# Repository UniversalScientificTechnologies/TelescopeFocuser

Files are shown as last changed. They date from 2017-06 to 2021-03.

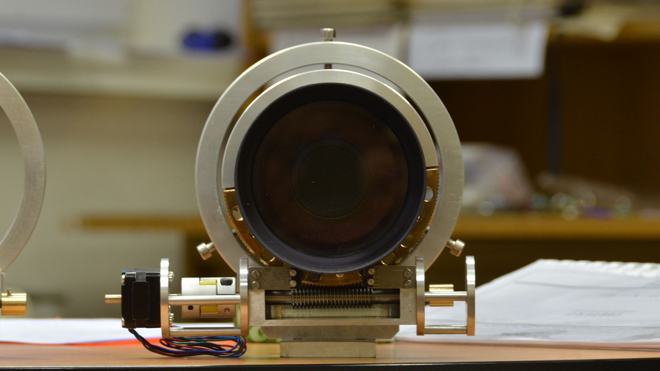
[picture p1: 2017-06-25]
DOC/SRC/img/DSC_8368x.JPG

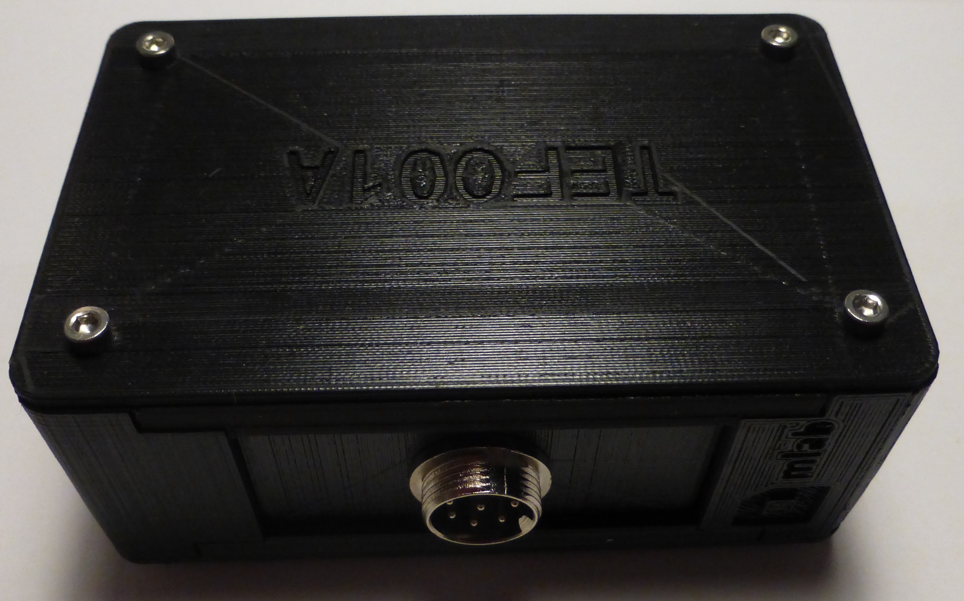
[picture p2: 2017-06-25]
DOC/SRC/img/P1020736.JPG

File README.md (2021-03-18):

# TelescopeFocuser
Telescope focuser with position feedback - TEFO01B

TEFO01B D50 telescope

# Mlab modules
 * HBSTEP01B
 * I2CSPI01A
 * RPS01A
 * USBI2C (optional)
 * POWERSOURCE

# Dependencies
 * [PyMLAB](https://github.com/MLAB-project/pymlab) with [HIDAPI](https://github.com/trezor/cython-hidapi)
 * [Axis class](https://github.com/MLAB-project/axis)

# Versions
There are two versions of code - the "simple one" (`TEFO_abspos.py`) and the "responsive one" (`TEFO_abspos_responsive.py`).
They only differ in the communication protocol and general behaviour, the other aspects are the same.

## The "simple" version (```TEFO_abspos.py```)
### Behaviour
Every successully recieved message is immediately confirmed with a simple response (see below).
The reply of the commands is sent after the completion (e.g., after the movement was accomplished). The deamon is not accepting commands until the previous operation is finished.

### Communication (UDP messages)
 * ```H``` Go to home position (defined in config json), reply: ```Home;<miss_calib>;```
 * ```CMxxxx``` parameter - calibrate and move to position in promile (0-1000), reply: ```CalibMove;<miss_calib>;```
 * ```Mxxxx``` move to position (without calibration), reply: ```Move;<miss_calib>;```
 * ```C``` run calibration, None reply
 * ```S``` Status, answer is in format ```<miss_calib>;<target>```

After every succesful recieve of message, inmediately command is confirmed with ```ACK;<command>;<senders_ip>;```

## The "responsive" version (```TEFO_abspos_responsive.py```)
### Behaviour and communication (UDP messages)
 * The daemon is responsive, i.e. every command is executed "in background", the execution does not wait for the completion.
 * The daemon never initiates any message, the communication is based on strict question/answer scheme.
 * Answer to any command consists of:
   * The command which initiated the answer (including the numerical ID)
   * Status of the request (accepted/duplicity/wrong)
   * Actual state of a motor (idle/moving/calibrating)
   * Result of the last movement (0=ok/1=fail)
   * Actual position (works even within the movement)
   * Actually set target position (if it does not equal actual position, the state of a motor is idle and the last movement's result is ok, it's obvious that the unit had been restarted; it's up to a client to send a recalibration command)
   * Expected time [s] till the end of ongoing move operation, only useful when state of a motor is "moving" (the lower estimate, typically takes ~0.1-0.2s more time to finish).
 * To take care of lossy UDP protocol, we use a simple logic: the daemon remembers the last command's ID. When the new command has the same ID, we expect that the client didn't receive the response, so we don't perform any operation, just respond the "duplicity" status and report the actual state. The ID is generated by a client, the daemon remembers only the ID of last command and doesn't take care of IP address. Which is OK for sparse communication with typically one client.
 * We use these commands:
   | Command | Description |
   | --- | --- |
   | `M<number_int>` | move to position |
   | `CM<number_int>` | calibrate and move to position |
   | `C` | calibrate and move to last or "home" position |
   | `S` | send status report |
   | `STOP` | stop all movements (emergency command for testing purposes) |
 * Structure of client's commands:
   `<ID_int16> <command>`
 * Structure of the response:
   `<ID_int16> <command> <request-status_string> <motor-status_string> <last-movement-result_int> <actual-ABS-position_int> <set-ABS-position_int> <time-to-moveend_float>`
 * The interruptibility:
   * `STOP` quits any movement
   * the calibration may be interrupted by nothing but stop
   * move comands may be interrupted by any command
   * non-accepted commands (which violated the interruptibility rules) cause response status "wrong"

## Connection
```nc -u localhost <port>```

# Configuration
Configuration is done by config [.json]() file.

```json

{
    "pymlab":{
        "i2c":{
            "device": "hid",
            "serial": "003347BC"
        },
        "bus": [
            { 
                "name":"spi", 
                "type":"i2cspi"
            },
            {
                "name": "encoder",
                "type": "rps01"
            }
        ]
    },
    "tefo":{
        "dir": 0,
        "lenght": 3300,
        "home": 1650,
        "speed": 100,
        "_lenght": 26500,
        "_home": 13250,
        "home_speed": 20 
    },
    "connection":{
        "ip": "127.0.0.1",
        "port": 5000
    }
}

```

# Installation of the systemd service
The example systemd service files are placed in SW/systemd.
The installation is simple, just copy the files to /etc/systemd/system 
and edit them to meet your needs (path, configurations of instances desired 
to run etc).

To apply changes made in the definition of systemd files:\
```systemctl daemon-reload```

To autostart the daemons after the boot:\
```systemctl enable mlab-tefo.target```

To manage an individual instance of service or the whole bunch use standard
systemctl interface, e.g.:\
```systemctl start mlab-tefo.target```\
```systemctl status mlab-tefo@focuser_D50_WF.service```\
```systemctl stop mlab-tefo@focuser_D50_main.service```

The output is redirected to the journal service, you can read it using the ```journalctl``` command.

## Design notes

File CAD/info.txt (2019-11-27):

Boxy pro TEFO01A

TEFO01A_BOX01A
-box vycházející z BASEBOX01A
-určen pro první část TEFO01A - HBSTEP01B, I2CSPI01A

TEFO01A_BOX02A_I2C
-box vycházející z BASEBOX01A
-určen pro druhou část ve variantě s I2C. Obsahuje moduly USBI2C01A,UNIPOWER02A, MIC338 (konektor)

TEFO01A_BOX02A_RS232
-box vycházející z BASEBOX01A
-určen pro druhou část ve variantě s RS232. Obsahuje moduly R232SINGLE01A, I2C232V01A, UNIPOWER02A, MIC338 (konektor)

Boxy pro TEFO01C

TEFO01C_BOX01A
-box vycházející z BASEBOX02A
-určen pro TEFO01C - HBSTEP01B, I2CSPI01A, UNIPOWER02A, USBI2C01A a konektor MIC338 pro připojení motoru.

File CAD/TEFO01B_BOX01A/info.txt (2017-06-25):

Box derived from BASEBOX01A
Intended for motor part of TEFO01B  with HBSTEP01B, I2CSPI01A,I2CDIFF01A modules

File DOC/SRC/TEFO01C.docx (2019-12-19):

Fokuser pro dalekohledy řízený přes USB

Jan Chroust, Roman Dvořák

## Konstrukce je určena pro automatické ostření dalekohledů. Elektronické řízení krokového motoru využívá mikrokrokování, které eliminuje vibrace generované motorem. Konstrukce počítá s koncovými spínači.

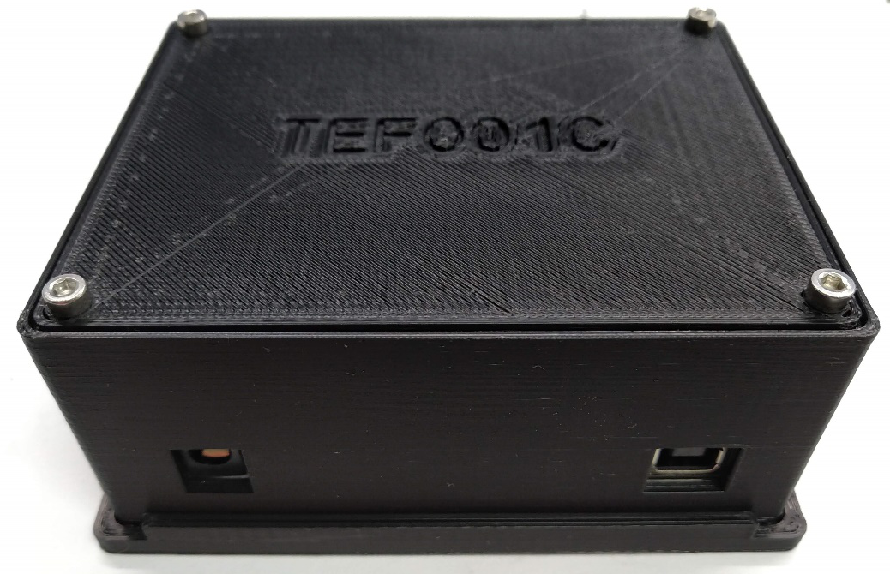
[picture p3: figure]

# 1. Technické parametry

Parametr | Hodnota | Poznámka
Napájení | 8 V – 45 V
Rozhraní | USB | Po dohodě
Rozměry | Dle zvolené koncepce

# 2. ¨ Popis konstrukce

### 2.1.1. Úvod

Zařízení TEFO01C řeší pouze elektronickou část fokuseru. Veškerou mechaniku je potřeba si vytvořit. K elektronice je možné připojit krokový motor v rozsahu napájecího napětí 8 V – 45 V. Mechanická konstrukce musí obsahovat dva koncové spínače, které budou mít jednu stranu kontaktů propojenou (po stisku koncového spínače musí být kontakt ve stavu sepnutém).

V případě zájmu o dodání TEFO01C nás prosím kontaktujte, protože konstrukce může být přizpůsobena požadavků. Je možné dodání více senzorů, ovládačů korkových motorů, nebo změnit komunikační rozhraní.

### 2.1.2. Potřebné moduly

Pro variantu řízenou USB: HBSTEP01B (s C pro 50V, jumper na ADCIN a VREG-VDD), I2CSPI01A, USBI2C01A (jumper na volbu 3V3 pro napájení I2C hřebínku a mezi VIO-3,3V), UNIPOWER02A(12V verze), TEFO01C_BOX01A

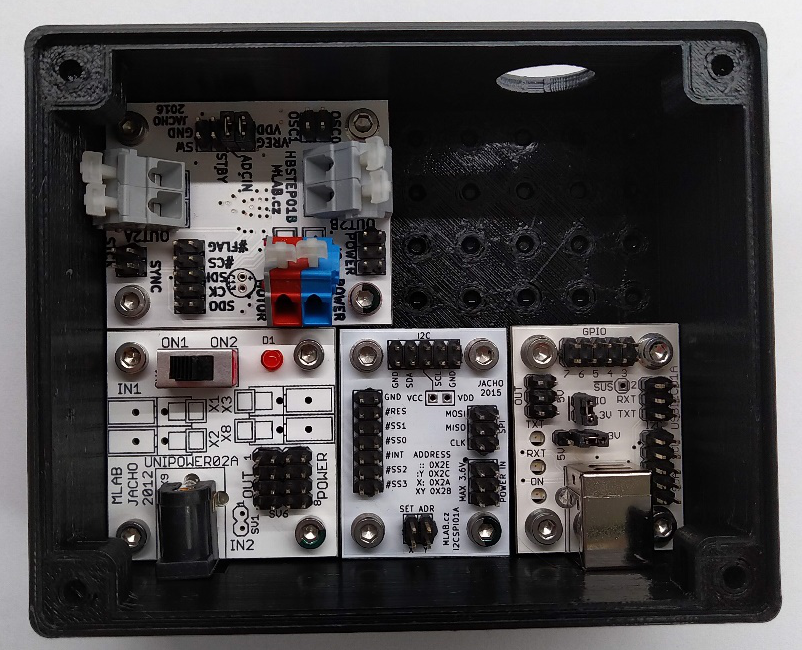
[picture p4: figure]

### 2.1.3. Propojení modulů

#### Zapojení konektoru MIC338

PIN – barva délka – význam vodiče – zapojení na modul

PIN 1 – oranžová 10 cm OUT1A - HBSTEP01B

PIN 2 – černá 10 cm – OUT2A - HBSTEP01B

PIN 3 – bílá 10 cm - OUT1B - HBSTEP01B

PIN 4 – modrá 10 cm - OUT2B - HBSTEP01B

PIN 5 – fialová 10 cm – první spínač GPIO0 (TXT) – USBI2C01A

PIN 6 – šedá 10cm – druhý spínač GPIO1 (RXT) – USBI2C01A

PIN 7 – zelná 10cm – střed mezi vypínači SW– HBSTEP01B

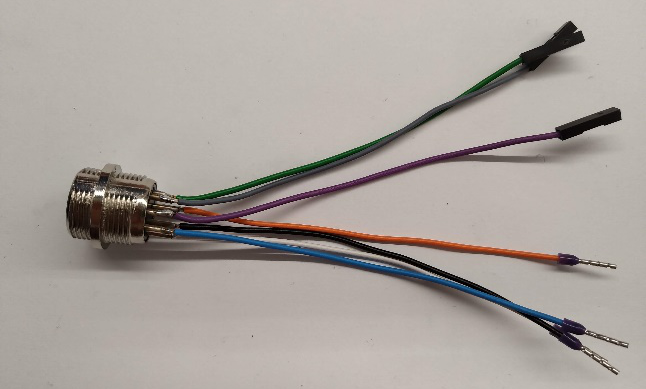
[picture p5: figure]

#### Propojení mezi moduly HBSTEP01B a I2CSPI01A

I2CSPI01A – HBSTEP01B

#SS0 - #CS – zelená 10cm

CLK – CK - bílá 10cm

MISO – SDO – šedá 10cm

MOSI – SDI – hnědá 10cm

Na I2CSPI01A vyvést vodičem napájení POWER IN na I2C hřebínek. Kvůli pull-up a napájení. 10Cm oranžová

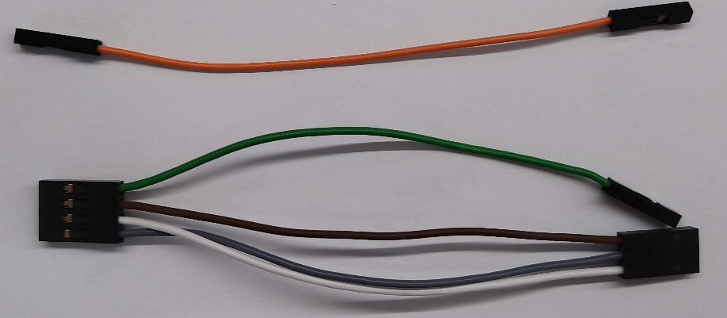
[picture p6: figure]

#### Propojení mezi USBI2C01A a I2CSPI01A

USBI2C01A – I2CSPI01A

SDA – SDA – bílá 10cm

SCL – SCL – hnědá 10cm

GND – GND – černá hřebínek pro I2C

VI2C – 3V3 – oranžová hřebínek pro I2C

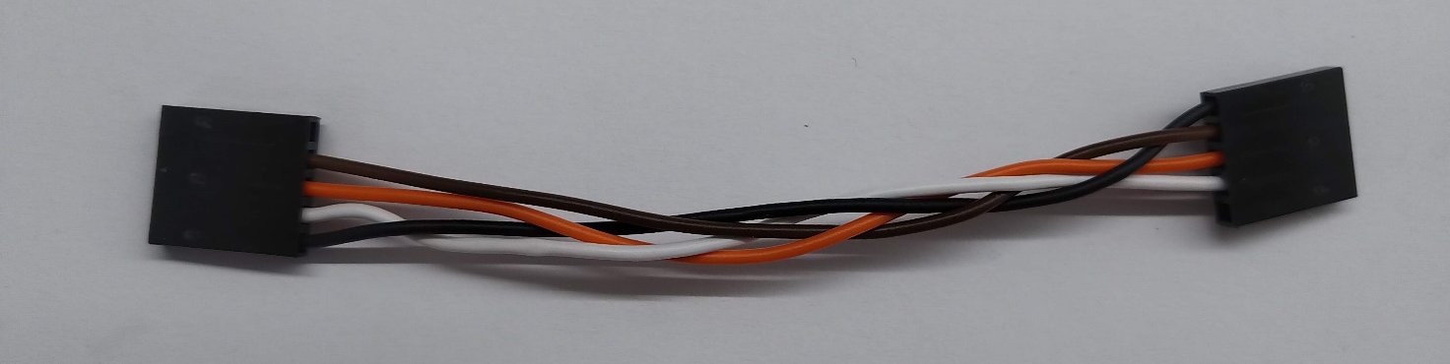
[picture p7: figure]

#### Propojení mezi UNIPOWER02A a HBSTEP01B napájení 12V

UNIPOWER02A – HBSTEP01B

POWER OUT (modré WAGO) - POWER MOTOR (modré WAGO) – 7cm modrá

POWER OUT (červené WAGO) + POWER MOTOR (červené WAGO) – 7cm žlutá

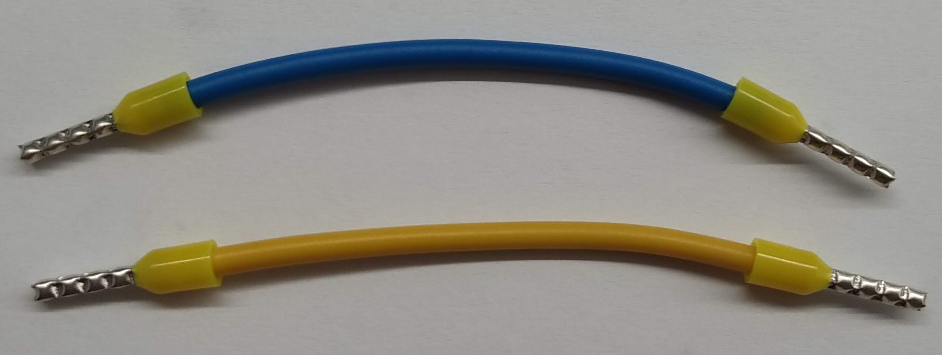
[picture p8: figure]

#### Propojení mezi HBSTEP01B a koncovým spínačem

Při dojezdu na koncoví spínač musí být kontakt v sepnutém stavu. Zapojení naznačuje následující obrázek:

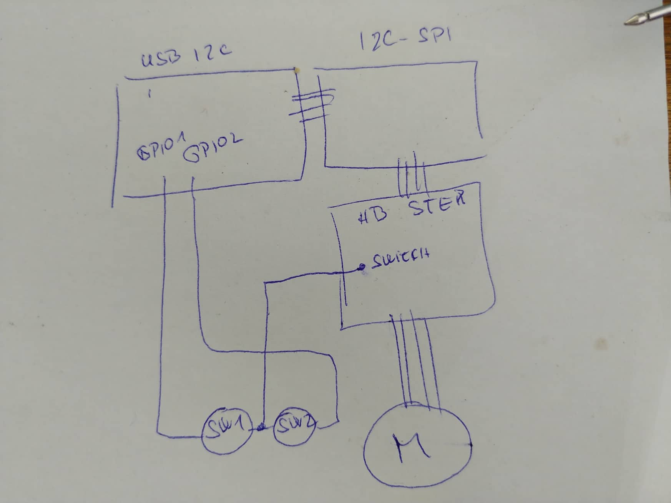
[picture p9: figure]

# 3. Fotografie

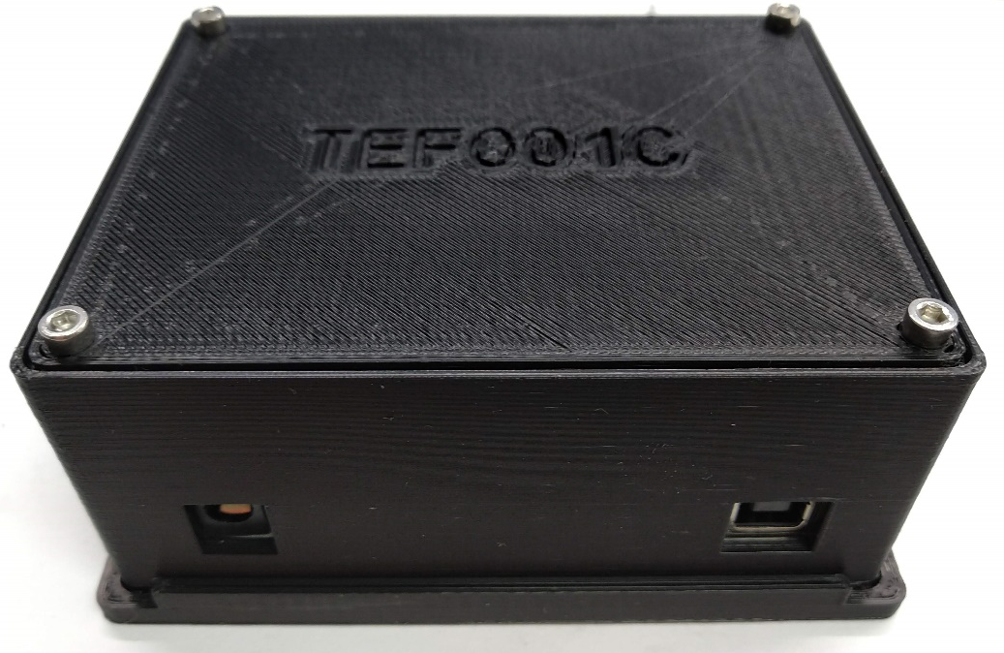
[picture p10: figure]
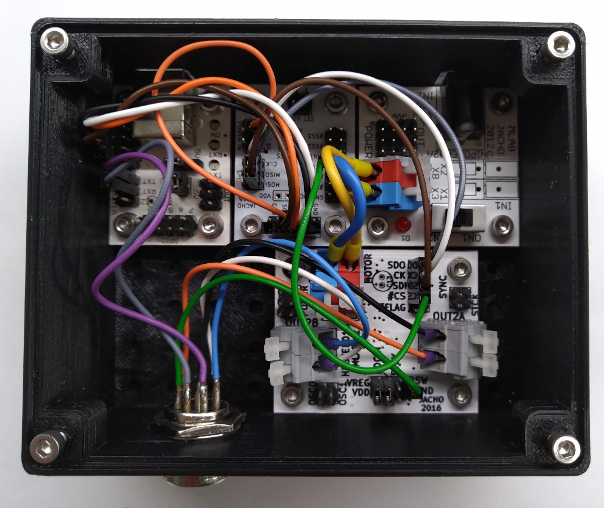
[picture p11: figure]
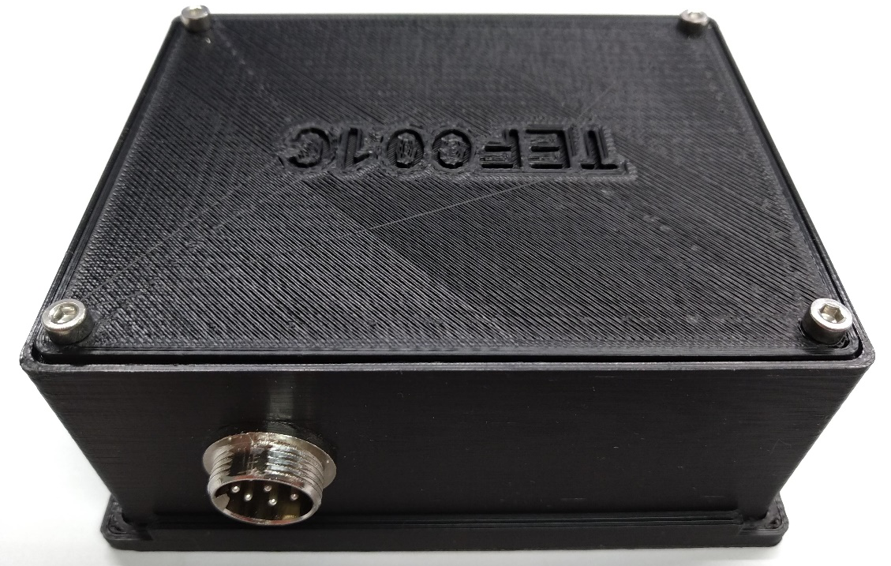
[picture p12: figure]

Ukázka vzhledu mechanické konstrukce:

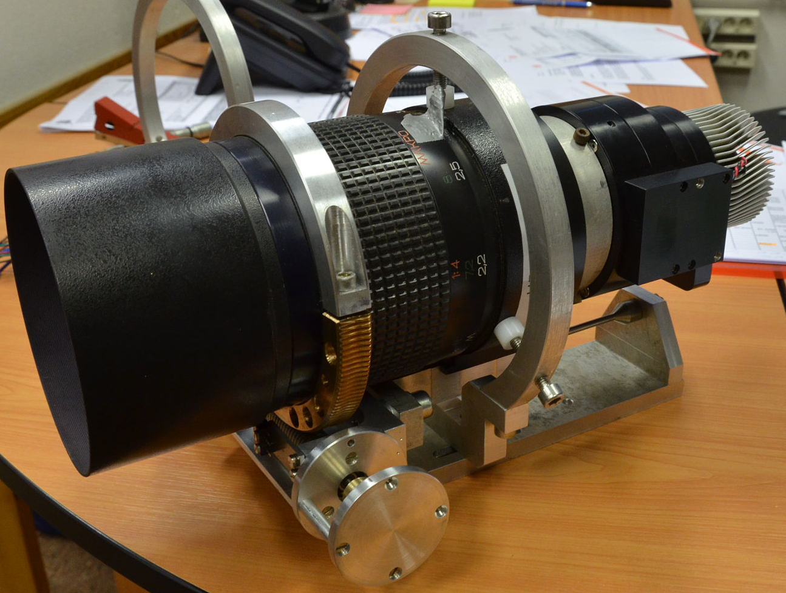
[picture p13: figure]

TEFO01C / 2015-12-21 / jacho/ http://www.mlab.cz 7 / 7

TEFO01C MLAB

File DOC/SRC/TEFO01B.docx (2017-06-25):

Fokuser pro dalekohledy řízený přes USB(RS232)

Jan Chroust, Jakub Kákona

Konstrukce je určena pro automatické ostření dalekohledů. Elektronické řízení krokového motoru využívá mikrokrokování, které eliminuje vibrace generované motorem. Konstrukce obsahuje senzor, který umožňuje dávat zpětnou vazbu o pohybu řízené hřídele, která ostří dalekohled. Konstrukce počítá s koncovými spínači.

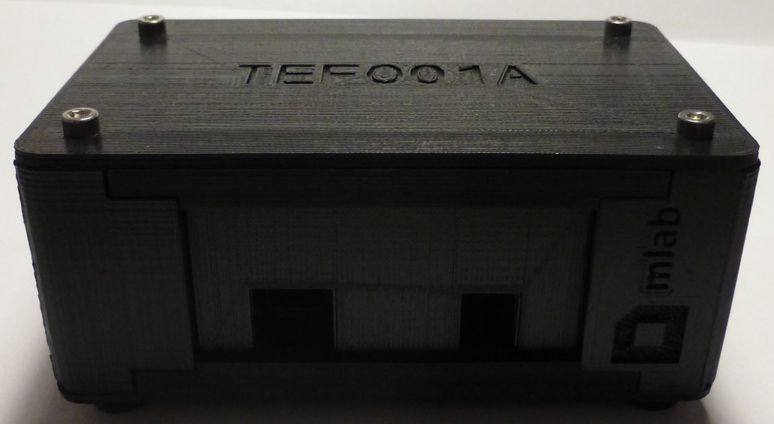
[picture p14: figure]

# 1. Technické parametry

Parametr | Hodnota | Poznámka
Napájení | 8 V – 45 V
Rozhraní | USB, RS232 | Po dohodě
Rozměry | Dle zvolené koncepce

# 2. Popis konstrukce

### 2.1.1. Úvod

Zařízení TEFO01A řeší pouze elektronickou část fokuseru. Veškerou mechaniku je potřeba si vytvořit. K elektronice je možné připojit krokový motor v rozsahu napájecího napětí 8 V – 45 V. Mechanická konstrukce musí obsahovat dva koncové spínače, které budou zapojeny paralelně (po stisku koncového spínače musí být kontakt ve stavu sepnutém). Konstrukce musí počítat s úchytem pro magnet o průměru 6 mm a výšce 5 mm v ose pohyblivé hřídele. Proti magnetu je potřeba zajistit úchyt modulu RPS01A.

V případě zájmu o dodání TEFO01A nás prosím kontaktujte, protože konstrukce může být přizpůsobena požadavků. Je možné dodání více senzorů, ovládačů korkových motorů, nebo změnit komunikační rozhraní.

### 2.1.2. Potřebné moduly

Pro variantu řízenou USB: HBSTEP01B (s C pro 50V, jumper na ADCIN a VREG-VDD), I2CSPI01A, USBI2C01A (jumper na volbu 3V3 pro napájení I2C hřebínku a mezi VIO-3,3V), UNIPOWER02A, RPS01A (3V3 verze), TEFO01A_BOX01A, TEFO01A_BOX02A_I2C

Pro variantu řízenou RS232: HBSTEP01B (s C pro 50V, jumper na ADCIN a VREG-VDD), I2CSPI01A, UNIPOWER02A, RPS01A (3V3 verze), I2C232V01A, RS232SINGLE01A, TEFO01A_BOX01A, TEFO01A_BOX02A_RS232

### 2.1.3. Propojení modulů verze s USB

#### Zapojení konektoru MIC338

PIN – barva délka – význam vodiče

PIN 1 – žlutá 15 cm + 3V3

PIN 2 – zelená 15 cm – 3V3

PIN 3 – černá 15 cm I2C SDA

PIN 4 – hnědá 15 cm I2C SCL

PIN 5 – modrá 15 cm - POWER MOTOR

PIN 8 – červená 15cm + POWER MOTOR

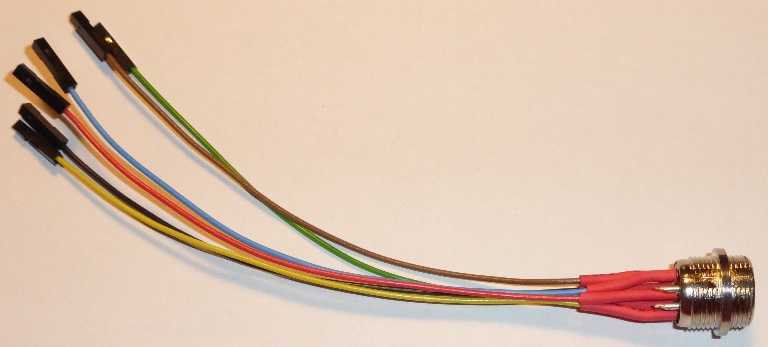
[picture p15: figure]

#### Propojení mezi moduly HBSTEP01B a I2CSPI01A v TEFO01A_BOX01A

I2CSPI01A – HBSTEP01B

#SS0 - #CS

CLK – CK

MISO – SDO

MOSI – SDI

Na I2CSPI01A vyvést vodičem napájení POWER IN na I2C hřebínek. Kvůli pull-up a napájení

#### Propojení mezi konektorem MIC338 a I2CSPI01A v TEFO01A_BOX01A

MIC338 – I2CSPI01A

PIN 1 (žlutá 15 cm + 3V3) – POWER IN (prostřední pin)

PIN 2 (zelená 15 cm GND) – POWER IN (krajní pin)

PIN 3 (černá 15 cm I2C SDA) - SDA

PIN 4 (hnědá 15 cm I2C SCL) - SCL

#### Propojení mezi konektorem MIC338 a HBSTEP01B v TEFO01A_BOX01A

MIC338 – HBSTEP01B

PIN 5 (modrá 15 cm) - POWER MOTOR (modré WAGO)

PIN 8 (červená 15cm) + POWER MOTOR (červené WAGO)

#### Propojení mezi RPS01A a I2CSPI01A

RPS01A – I2CSPI01A

SDA – SDA

SCL – SCL

GND – GND – hřebínek pro I2C

VI2C – 3V3 – hřebínek pro I2C

#### Propojení mezi HBSTEP01B a koncovým spínačem

Koncové spínače spojit paralelně. Při dojezdu na koncoví spínač musí být kontakt v sepnutém stavu.

#### Propojení mezi konektorem MIC338 a USBI2C01A v TEFO01A_BOX02A_I2C

MIC338 – USBI2C01A

PIN 1 (žlutá 15 cm + 3V3) + 3V3 z I2C hřebínku

PIN 2 (zelená 15 cm GND) GND z I2C hřebínku

PIN 3 (černá 15 cm I2C SDA) - SDA

PIN 4 (hnědá 15 cm I2C SCL) – SCL

#### Propojení mezi konektorem MIC338 a UNIPOWER02A v TEFO01A_BOX02A_I2C

MIC338 – UNIPOWER02A

PIN 5 (modrá 15 cm) - POWER OUT (modré WAGO)

PIN 8 (červená 15cm) + POWER OUT (červené WAGO)

# 3. Fotografie

Vnitřní zapojení v TEFO01A_BOX01A:

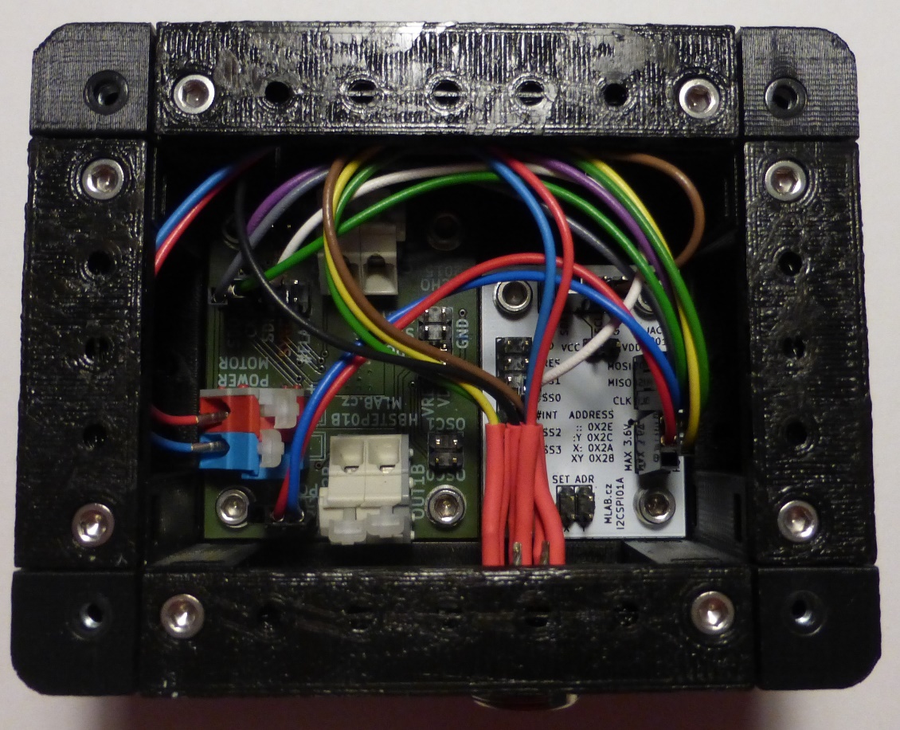
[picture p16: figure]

Vnitřní zapojení v TEFO01A_BOX02A_I2C:

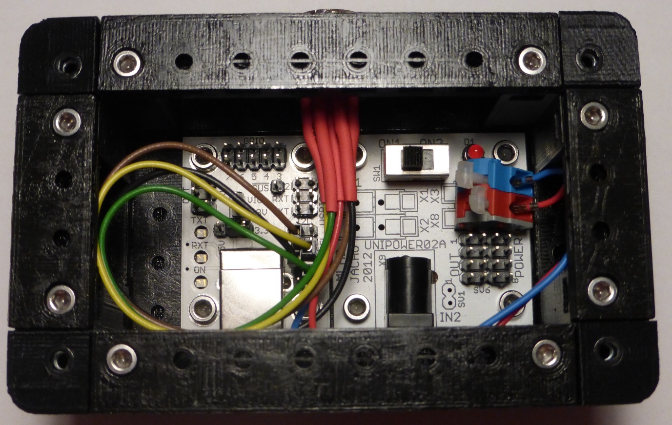
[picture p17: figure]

Ukázka vzhledu mechanické konstrukce:


TEFO01A / 2015-12-21 / jacho/ http://www.mlab.cz 5 / 6

TEFO01A MLAB

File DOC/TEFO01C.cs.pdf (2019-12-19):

TEFO01C | MLAB

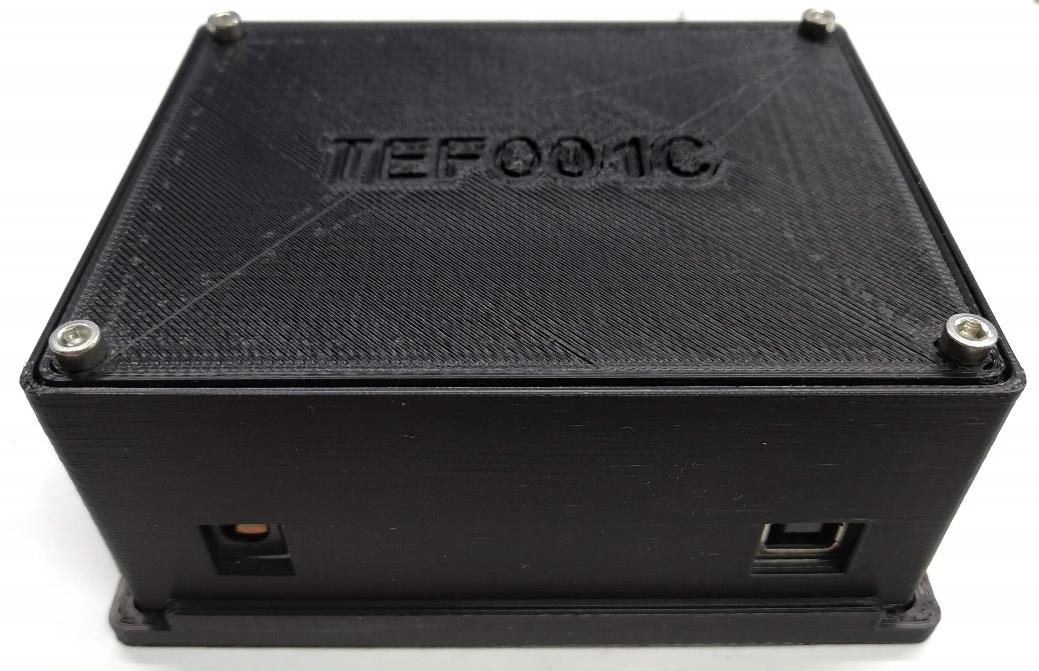
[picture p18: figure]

TEFO01C / 2015-12-21 / jacho/ http://www.mlab.cz | 1 / 7

# Fokuser pro dalekohledy řízený přes USB

Jan Chroust, Roman Dvořák

Konstrukce je určena pro automatické ostření dalekohledů.

### Elektronické řízení krokového motoru využívá mikrokrokování, které eliminuje vibrace generované motorem. Konstrukce počítá s

koncovými spínači.

# 1. Technické parametry

Parametr | Hodnota | Poznámka
Napájení | 8 V – 45 V
Rozhraní | USB | Po dohodě
Rozměry | Dle zvolené koncepce

TEFO01C | MLAB

# 2. ¨ Popis konstrukce

### 2.1.1. Úvod

Zařízení TEFO01C řeší pouze elektronickou část fokuseru. Veškerou mechaniku je potřeba si vytvořit. K elektronice je možné připojit krokový motor v rozsahu napájecího napětí 8 V – 45 V. Mechanická konstrukce musí obsahovat dva koncové spínače, které budou mít jednu stranu kontaktů propojenou (po stisku koncového spínače musí být kontakt ve stavu sepnutém).

V případě zájmu o dodání TEFO01C nás prosím kontaktujte, protože konstrukce může být přizpůsobena požadavků. Je možné dodání více senzorů, ovládačů korkových motorů, nebo změnit komunikační rozhraní.

### 2.1.2. Potřebné moduly

Pro variantu řízenou USB: HBSTEP01B (s C pro 50V, jumper na ADCIN a VREG-VDD), I2CSPI01A, USBI2C01A (jumper na volbu 3V3 pro napájení I2C hřebínku a mezi VIO-3,3V), UNIPOWER02A(12V verze), TEFO01C_BOX01A

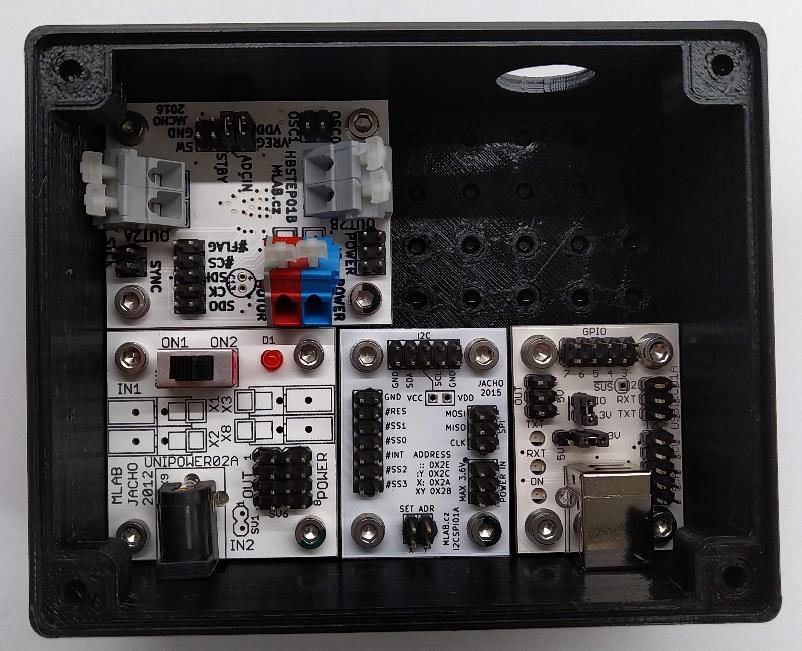
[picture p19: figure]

TEFO01C | MLAB

### 2.1.3. Propojení modulů

Zapojení konektoru MIC338

PIN – barva délka – význam vodiče – zapojení na modul

PIN 1 – oranžová 10 cm OUT1A - HBSTEP01B

PIN 2 – černá 10 cm – OUT2A - HBSTEP01B

PIN 3 – bílá 10 cm - OUT1B - HBSTEP01B

PIN 4 – modrá 10 cm - OUT2B - HBSTEP01B

PIN 5 – fialová 10 cm – první spínač GPIO0 (TXT) – USBI2C01A

PIN 6 – šedá 10cm – druhý spínač GPIO1 (RXT) – USBI2C01A

PIN 7 – zelná 10cm – střed mezi vypínači SW– HBSTEP01B

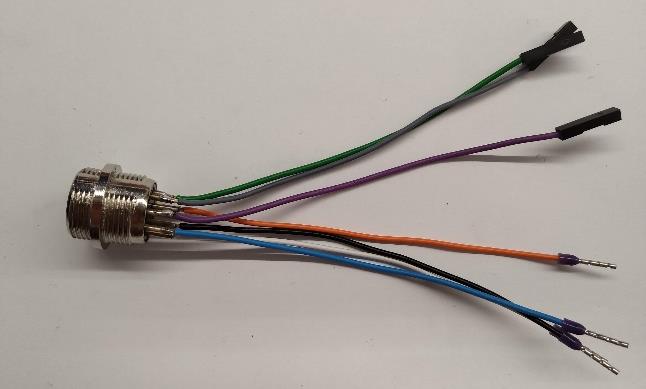
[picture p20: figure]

Propojení mezi moduly HBSTEP01B a I2CSPI01A

I2CSPI01A – HBSTEP01B

#SS0 - #CS – zelená 10cm

CLK – CK - bílá 10cm

MISO – SDO – šedá 10cm

MOSI – SDI – hnědá 10cm

Na I2CSPI01A vyvést vodičem napájení POWER IN na I2C hřebínek. Kvůli pull-up a napájení. 10Cm oranžová

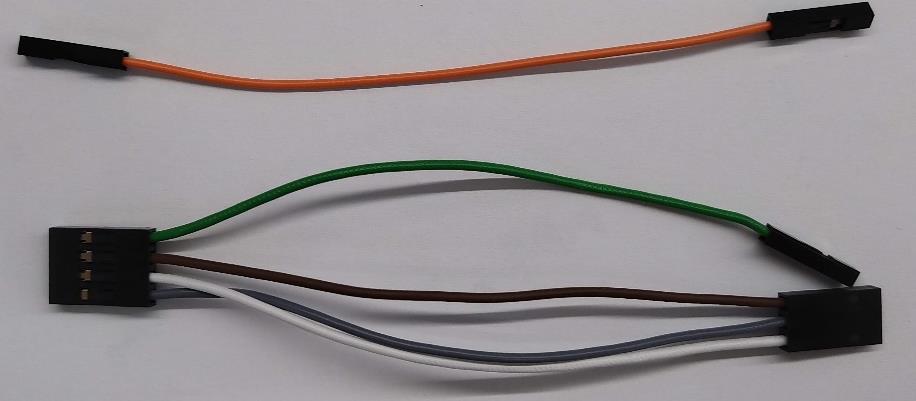
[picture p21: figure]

TEFO01C | MLAB

Propojení mezi USBI2C01A a I2CSPI01A

USBI2C01A – I2CSPI01A

SDA – SDA – bílá 10cm

SCL – SCL – hnědá 10cm

GND – GND – černá hřebínek pro I2C

VI2C – 3V3 – oranžová hřebínek pro I2C

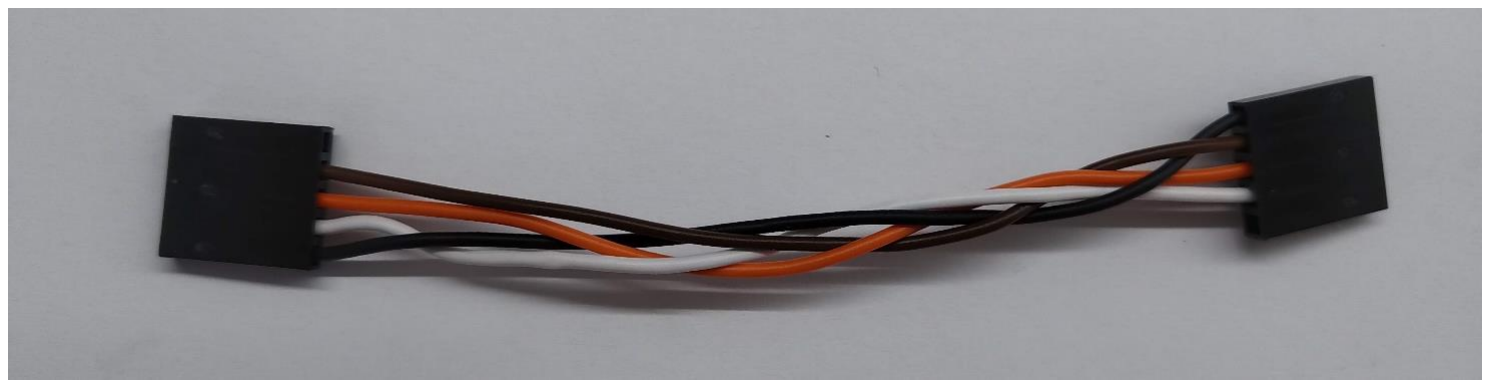
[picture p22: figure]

Propojení mezi UNIPOWER02A a HBSTEP01B napájení 12V

UNIPOWER02A – HBSTEP01B

POWER OUT (modré WAGO) - POWER MOTOR (modré WAGO) – 7cm modrá

POWER OUT (červené WAGO) + POWER MOTOR (červené WAGO) – 7cm žlutá

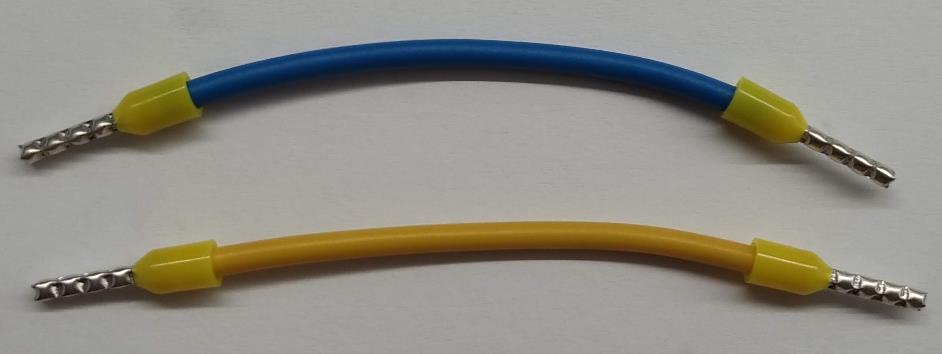
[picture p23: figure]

TEFO01C | MLAB

Propojení mezi HBSTEP01B a koncovým spínačem

Při dojezdu na koncoví spínač musí být kontakt v sepnutém stavu. Zapojení naznačuje následující obrázek:

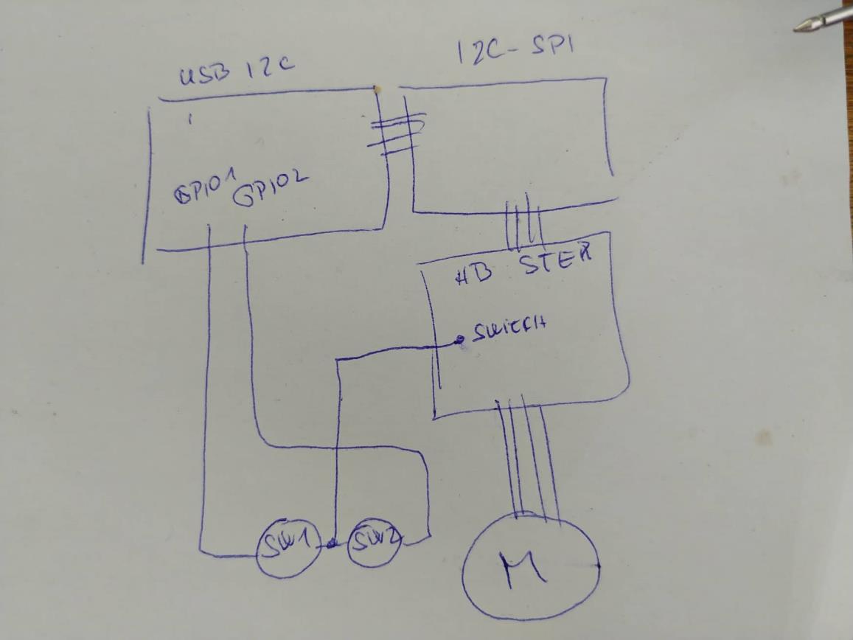
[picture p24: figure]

TEFO01C | MLAB

# 3. Fotografie

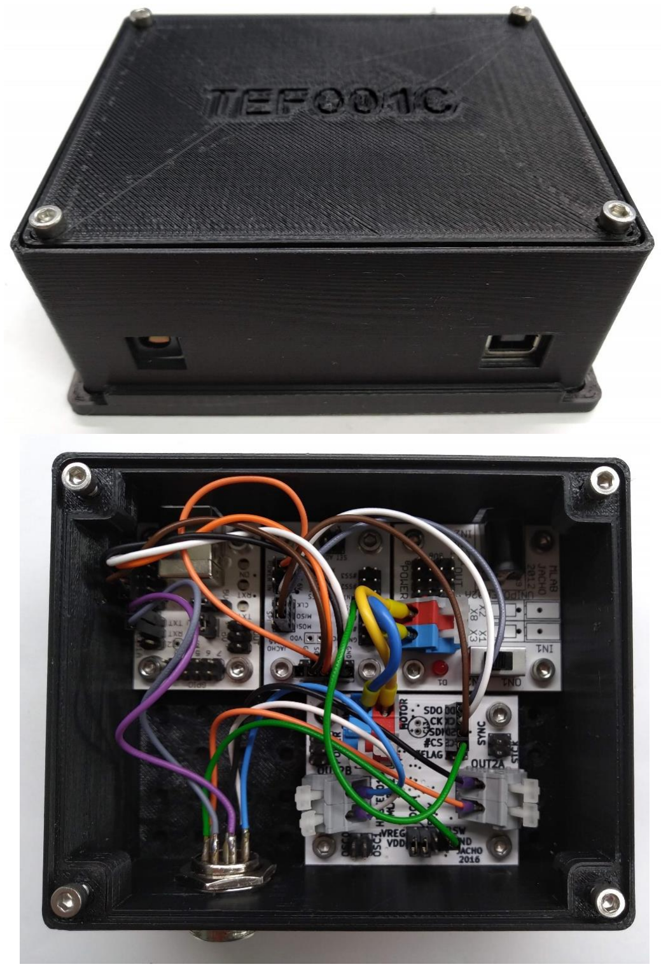
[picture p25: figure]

TEFO01C | MLAB

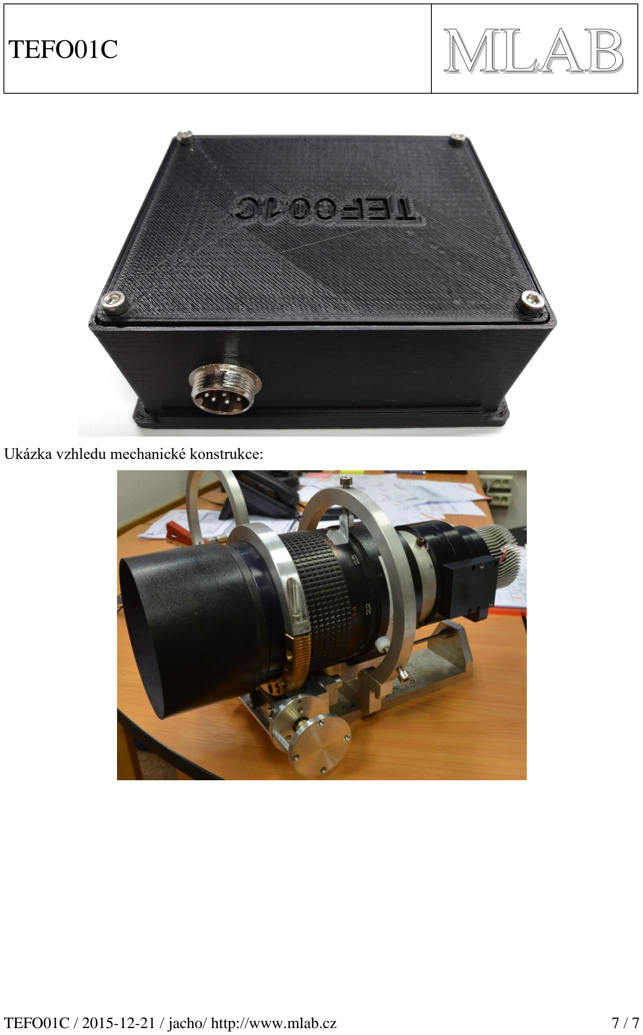
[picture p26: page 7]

Ukázka vzhledu mechanické konstrukce:

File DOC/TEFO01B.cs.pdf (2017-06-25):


TEFO01A / 2015-12-21 / jacho/ http://www.mlab.cz | 1 / 6
TEFO01A | MLAB

# Fokuser pro dalekohledy řízený přes USB(RS232)

Jan Chroust, Jakub Kákona

Konstrukce je určena pro automatické ostření dalekohledů.

### Elektronické řízení krokového motoru využívá mikrokrokování, které eliminuje vibrace generované motorem. Konstrukce obsahuje senzor, který umožňuje dávat zpětnou vazbu o pohybu řízené hřídele, která ostří dalekohled. Konstrukce počítá s koncovými

spínači.

# 1. Technické parametry

Parametr | Hodnota | Poznámka
Napájení | 8 V – 45 V
Rozhraní | USB, RS232 | Po dohodě
Rozměry | Dle zvolené koncepce

TEFO01A | MLAB

# 2. Popis konstrukce

### 2.1.1. Úvod

Zařízení TEFO01A řeší pouze elektronickou část fokuseru. Veškerou mechaniku je potřeba si vytvořit. K elektronice je možné připojit krokový motor v rozsahu napájecího napětí 8 V – 45 V. Mechanická konstrukce musí obsahovat dva koncové spínače, které budou zapojeny paralelně (po stisku koncového spínače musí být kontakt ve stavu sepnutém). Konstrukce musí počítat s úchytem pro magnet o průměru 6 mm a výšce 5 mm v ose pohyblivé hřídele. Proti magnetu je potřeba zajistit úchyt modulu RPS01A.

V případě zájmu o dodání TEFO01A nás prosím kontaktujte, protože konstrukce může být přizpůsobena požadavků. Je možné dodání více senzorů, ovládačů korkových motorů, nebo změnit komunikační rozhraní.

### 2.1.2. Potřebné moduly

Pro variantu řízenou USB: HBSTEP01B (s C pro 50V, jumper na ADCIN a VREG-VDD), I2CSPI01A, USBI2C01A (jumper na volbu 3V3 pro napájení I2C hřebínku a mezi VIO-3,3V), UNIPOWER02A, RPS01A (3V3 verze), TEFO01A_BOX01A, TEFO01A_BOX02A_I2C

Pro variantu řízenou RS232: HBSTEP01B (s C pro 50V, jumper na ADCIN a VREG-VDD), I2CSPI01A, UNIPOWER02A, RPS01A (3V3 verze), I2C232V01A, RS232SINGLE01A, TEFO01A_BOX01A, TEFO01A_BOX02A_RS232

### 2.1.3. Propojení modulů verze s USB

Zapojení konektoru MIC338

PIN – barva délka – význam vodiče

PIN 1 – žlutá 15 cm + 3V3

PIN 2 – zelená 15 cm – 3V3

PIN 3 – černá 15 cm I2C SDA

PIN 4 – hnědá 15 cm I2C SCL

PIN 5 – modrá 15 cm - POWER MOTOR

PIN 8 – červená 15cm + POWER MOTOR


TEFO01A | MLAB

Propojení mezi moduly HBSTEP01B a I2CSPI01A v TEFO01A_BOX01A

I2CSPI01A – HBSTEP01B

#SS0 - #CS

CLK – CK

MISO – SDO

MOSI – SDI

Na I2CSPI01A vyvést vodičem napájení POWER IN na I2C hřebínek. Kvůli pull-up a napájení

Propojení mezi konektorem MIC338 a I2CSPI01A v TEFO01A_BOX01A

MIC338 – I2CSPI01A

PIN 1 (žlutá 15 cm + 3V3) – POWER IN (prostřední pin)

PIN 2 (zelená 15 cm GND) – POWER IN (krajní pin)

PIN 3 (černá 15 cm I2C SDA) - SDA

PIN 4 (hnědá 15 cm I2C SCL) - SCL

Propojení mezi konektorem MIC338 a HBSTEP01B v TEFO01A_BOX01A

MIC338 – HBSTEP01B

PIN 5 (modrá 15 cm) - POWER MOTOR (modré WAGO)

PIN 8 (červená 15cm) + POWER MOTOR (červené WAGO)

Propojení mezi RPS01A a I2CSPI01A

RPS01A – I2CSPI01A

SDA – SDA

SCL – SCL

GND – GND – hřebínek pro I2C

VI2C – 3V3 – hřebínek pro I2C

Propojení mezi HBSTEP01B a koncovým spínačem

Koncové spínače spojit paralelně. Při dojezdu na koncoví spínač musí být kontakt v sepnutém stavu.

TEFO01A | MLAB

Propojení mezi konektorem MIC338 a USBI2C01A v TEFO01A_BOX02A_I2C

MIC338 – USBI2C01A

PIN 1 (žlutá 15 cm + 3V3) + 3V3 z I2C hřebínku

PIN 2 (zelená 15 cm GND) GND z I2C hřebínku

PIN 3 (černá 15 cm I2C SDA) - SDA

PIN 4 (hnědá 15 cm I2C SCL) – SCL

Propojení mezi konektorem MIC338 a UNIPOWER02A v TEFO01A_BOX02A_I2C

MIC338 – UNIPOWER02A

PIN 5 (modrá 15 cm) - POWER OUT (modré WAGO)

PIN 8 (červená 15cm) + POWER OUT (červené WAGO)

TEFO01A | MLAB

# 3. Fotografie


Vnitřní zapojení v TEFO01A_BOX01A:

Vnitřní zapojení v TEFO01A_BOX02A_I2C:

TEFO01A | MLAB

Ukázka vzhledu mechanické konstrukce:


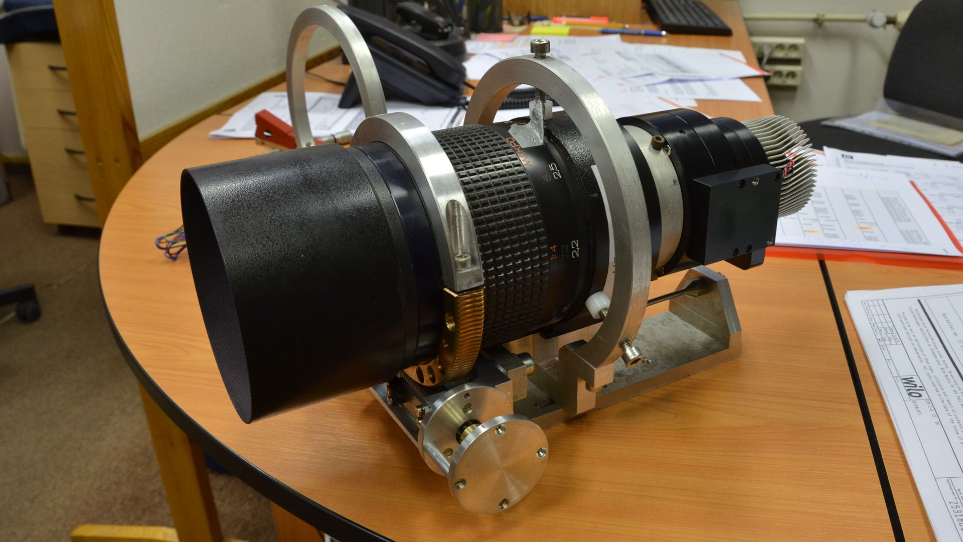
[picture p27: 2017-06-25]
DOC/SRC/img/DSC_8369x.JPG

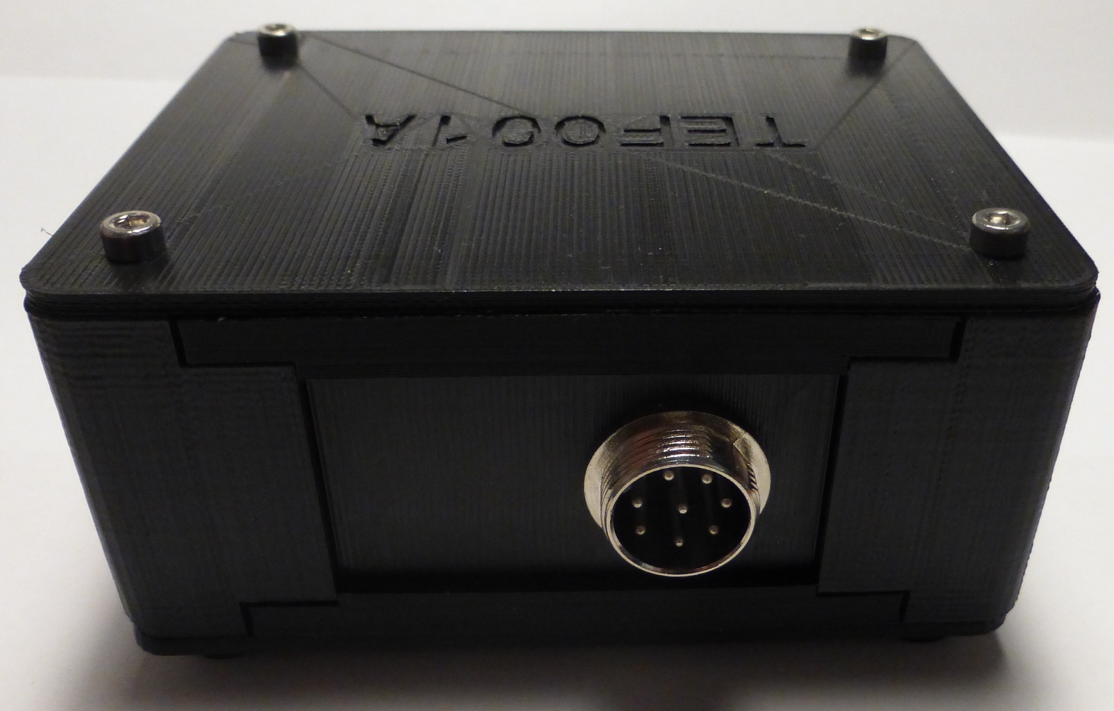
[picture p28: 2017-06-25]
TEFO01B_Small.JPG

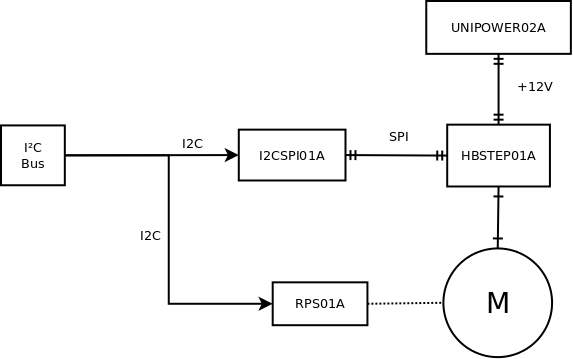
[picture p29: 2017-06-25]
DOC/SRC/TEFO.png

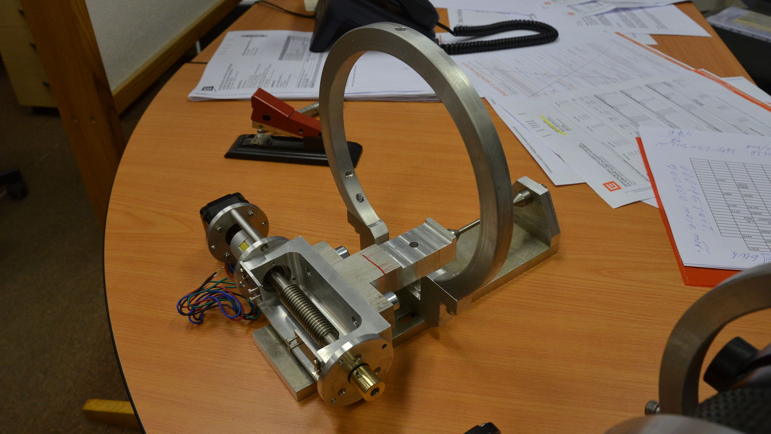
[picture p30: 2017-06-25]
DOC/SRC/img/DSC_8370x.JPG

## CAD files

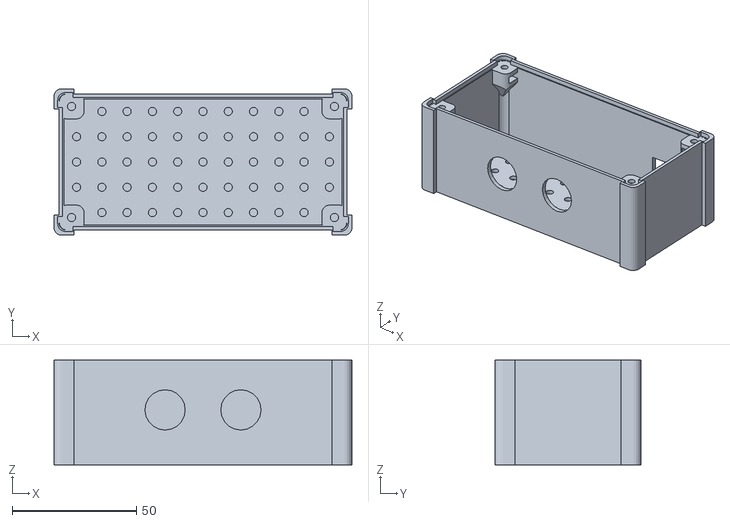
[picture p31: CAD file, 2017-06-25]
CAD/TEFO01B_BOX01A/AMF/TEFO01B_BOX01A.stl
119.8 x 58.8 x 42.1

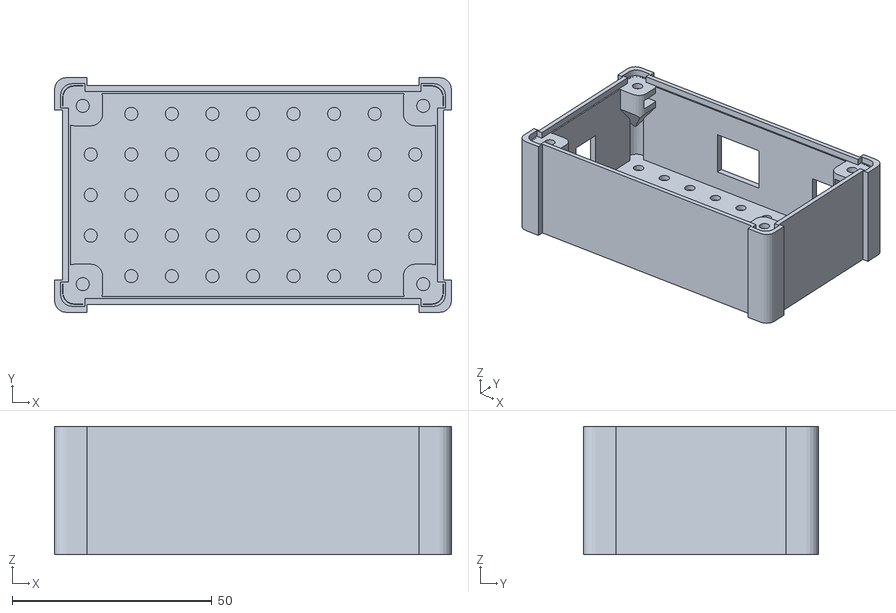
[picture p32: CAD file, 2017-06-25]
CAD/TEFO01B_BOX02A_USB/AMF/TEFO01B_BOX02A_USB.stl
99.4 x 58.8 x 32.1

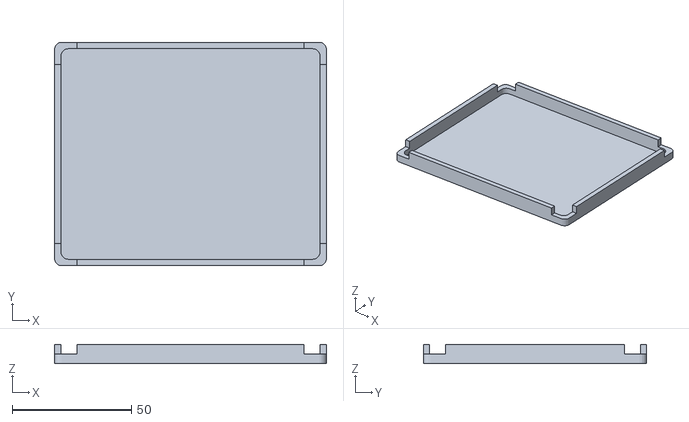
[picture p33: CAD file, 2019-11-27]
CAD/TEFO01C_BOX01A/amf/TEFO01C_BOX01A_bot.stl
113.8 x 93.5 x 8.10

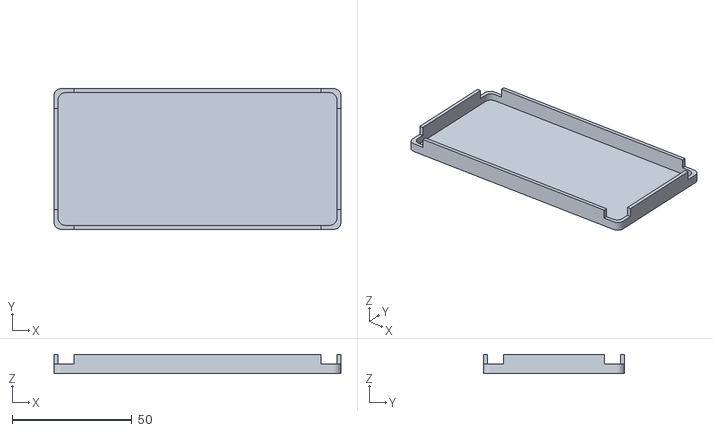
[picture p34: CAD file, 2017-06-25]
CAD/TEFO01B_BOX01A/AMF/TEFO01B_BOX01A_kryt.stl
119.8 x 58.8 x 8.10

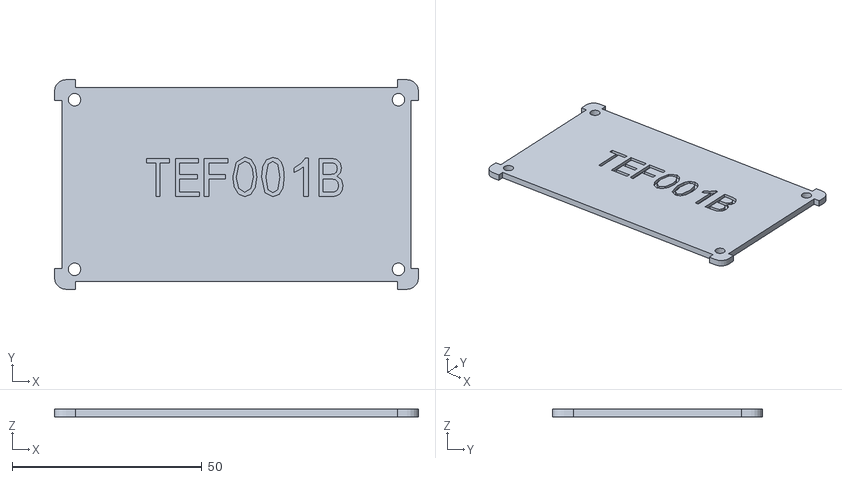
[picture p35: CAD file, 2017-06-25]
CAD/TEFO01B_BOX02A_USB/AMF/TEFO01B_BOX02A_USB_PLBASE_top.stl
95.8 x 55.2 x 2.00

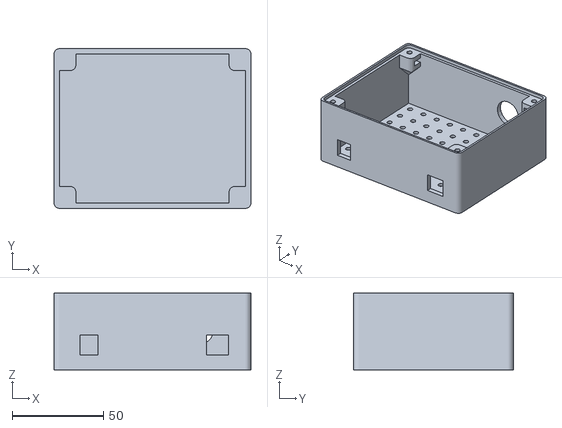
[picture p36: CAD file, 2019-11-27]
CAD/TEFO01C_BOX01A/amf/TEFO01C_BOX01A.stl
107.8 x 87.5 x 42.1

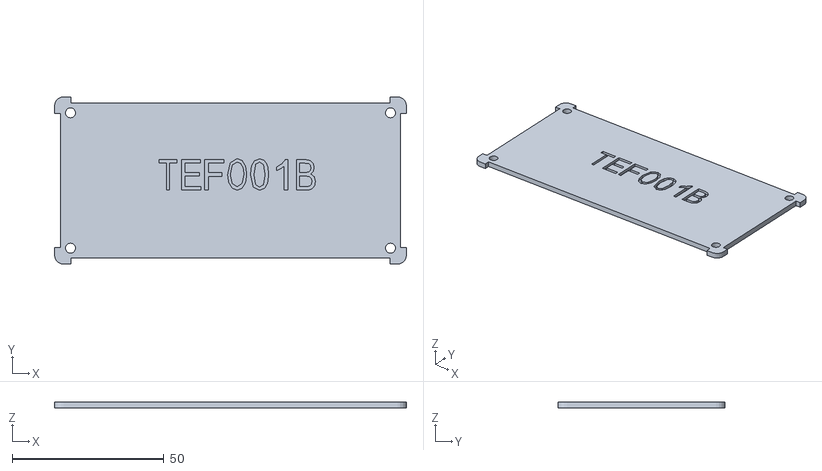
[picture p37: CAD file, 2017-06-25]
CAD/TEFO01B_BOX01A/AMF/TEFO01B_BOX01A_PLBASE_top.stl
116.2 x 55.2 x 2.00

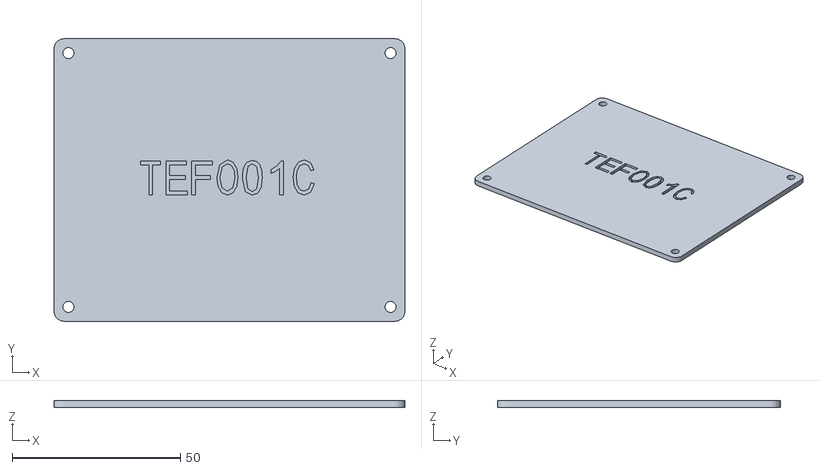
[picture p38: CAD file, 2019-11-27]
CAD/TEFO01C_BOX01A/amf/TEFO01C_BOX01A_top.stl
104.4 x 84.1 x 2.10

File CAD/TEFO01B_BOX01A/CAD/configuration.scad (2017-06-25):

//Název boxu (zařízení)
box_jmeno="TEFO01B";

//ALBASE1115
//------------------------------------------------------------
///*
vzdalenost_der = 10.16; //rozteč děr mezi sebou
radidus_hrany = 3; //radius zaobleni sloupku

//parametry lišty
vzdalenost_od_okraje = 5.08; //vzdalenost stredu upevnovaci diry od kraje desky

//mala hrana
pocet_der1 = 5; //pocet děr v ose y

//velka hrana
pocet_der2 = 11; //pocet der v ose x
//*/


//OBECNE PARAMETRY KRABICKY
//------------------------------------------------------------
//BOCNICE
vyska_bocnice=40;
tloustka_bocnice=2;

//PLBASE PARAMETRY
//------------------------------------------------------------
tloustka_plbase = 2; //tloustka plbase
prekryti_der=0.3; //sila materiálu, který překrývá díry

plbase_tolerance_horni=0.0; //pro zvětšení tolerance aby tam šlo dát  horní čelíčko

//PRIPADNA VYSKA NOZICEK
//------------------------------------------------------------
vyska_nozicky=5;

//Rozmery loga MLAB
//------------------------------------------------------------
logo_vyska=0.15;
logo_sirka=0.15;

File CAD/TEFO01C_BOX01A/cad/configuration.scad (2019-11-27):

//Název boxu (zařízení)
box_jmeno="TEFO01C";

vzdalenost_der = 10.16; //rozteč děr mezi sebou
radidus_hrany = 3; //radius zaobleni sloupku
vzdalenost_od_okraje = 5.2; //vzdalenost stredu upevnovaci diry od kraje desky
pocet_der1 = 8; //pocet děr v ose y
pocet_der2 = 10; //pocet der v ose x



//OBECNE PARAMETRY KRABICKY
//------------------------------------------------------------
//BOCNICE
vyska_bocnice=40;
tloustka_bocnice=3;


//PLBASE PARAMETRY
//------------------------------------------------------------
tloustka_plbase = 2; //tloustka plbase - dna
prekryti_der=0.2; //sila materiálu, který překrývá díry, aby nebyli vidět

plbase_tolerance_horni=0.5; //pro zvětšení tolerance aby tam šlo dát  horní čelíčko


//Rozmery loga MLAB
//------------------------------------------------------------
logo_vyska=0.15;
logo_sirka=0.15;

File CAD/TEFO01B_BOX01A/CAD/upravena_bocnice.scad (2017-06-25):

use <configuration/bocnice.scad>

use <configuration/otvory.scad>
use <configuration/plbase.scad>
include <configuration/manufactury_conf.scad>
include <configuration.scad>
include <configuration/otvory_conf.scad>

upravena_bocnice();

//Slouzi pro vytvoreni vlastnich celicek dle potreby

//Vytvoreni predniho celicka krabicky
//--------------------------------------------------------
module upravena_bocnice()
{
difference() {
    union() {
    bocnice(pocet_der1-1,pocet_der2-1,radidus_hrany,vzdalenost_der,vzdalenost_od_okraje,prumer_sroubu,vyska_bocnice,prekryti_der,tloustka_bocnice);

translate([-((pocet_der2-1)*vzdalenost_der+2*vzdalenost_od_okraje)/2-tloustka_bocnice,-vzdalenost_od_okraje-tloustka_bocnice,-(vyska_bocnice/2)])
rotate(a=[180,0,90])


plbase(pocet_der1,pocet_der2,radidus_hrany,vzdalenost_der,vzdalenost_od_okraje,prumer_sroubu,tloustka_plbase,prekryti_der,tloustka_bocnice);
        
           }
            union() {
//Vytvoreni otvorů v přední stěně
//--------------------------------------------------------
                
                translate([-((pocet_der2-1)*vzdalenost_der)/2,-vzdalenost_od_okraje-tloustka_bocnice/2,-(vyska_bocnice/2)])
                {
                //složí k posunu otvoru v násobku děr
                  
                    posun_p2=6.5;    
                    translate([posun_p2*vzdalenost_der,0,0])   
                      MIC338(tloustka_bocnice,vzdalenost_der,vyska_bocnice);
                    
                    posun_p3=3.5;    
                    translate([posun_p3*vzdalenost_der,0,0])   
                      MIC338(tloustka_bocnice,vzdalenost_der,vyska_bocnice);
                    
                }
}



//Vytvoreni zadniho celicka krabicky
//--------------------------------------------------------


                translate([((pocet_der2-1)*vzdalenost_der)/2,(pocet_der1-1)*vzdalenost_der+vzdalenost_od_okraje+tloustka_bocnice/2,-(vyska_bocnice/2)])
                {
               
                      
    
                    posun_z2=0;    
                    
                    translate([-posun_z2*vzdalenost_der,0,0])  
                   rotate(a=[0,0,180])  
                        I2CDIFF01A(tloustka_bocnice,vzdalenost_der);
                    
                   
                    
                    
                }
}



//Vytvoreni leveho celicka krabicky
//--------------------------------------------------------



//Vytvoreni praveho celicka krabicky
//--------------------------------------------------------


}

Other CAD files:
CAD/TEFO01C_BOX01A/cad/src/text/Letters.dxf
CAD/TEFO01B_BOX01A/CAD/configuration/text/Letters.dxf
CAD/TEFO01B_BOX02A_USB/CAD/configuration/text/Letters.dxf
CAD/TEFO01B_BOX02A_USB/CAD/configuration.scad
CAD/TEFO01B_BOX01A/CAD/assembly.scad
CAD/TEFO01B_BOX01A/CAD/configuration/bocnice.scad
CAD/TEFO01B_BOX01A/CAD/configuration/lista.scad
CAD/TEFO01B_BOX01A/CAD/configuration/manufactury_conf.scad
CAD/TEFO01B_BOX01A/CAD/configuration/otvory.scad
CAD/TEFO01B_BOX01A/CAD/configuration/otvory_conf.scad
CAD/TEFO01B_BOX01A/CAD/configuration/plbase.scad
CAD/TEFO01B_BOX01A/CAD/configuration/sloupek.scad
CAD/TEFO01B_BOX01A/CAD/configuration/spodni_kryt.scad
CAD/TEFO01B_BOX01A/CAD/configuration/text/Write.scad
CAD/TEFO01B_BOX01A/CAD/print_data/TEFO01B_BOX01A.scad
CAD/TEFO01B_BOX01A/CAD/print_data/TEFO01B_BOX01A_PLBASE_top.scad
CAD/TEFO01B_BOX01A/CAD/print_data/TEFO01B_BOX01A_kryt.scad
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

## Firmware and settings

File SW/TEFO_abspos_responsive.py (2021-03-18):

#!/usr/bin/python

#import logging
#logging.basicConfig(level=logging.DEBUG)

import sys
import time
import axis
import socket
import select
from pymlab import config
import json
import math


class focuser():

    def __init__(self):

        config_file = 'focuser.json'
        if len(sys.argv) == 2:
            config_file = sys.argv[1]

        print("Using config file:", config_file)

        with open(config_file) as data_file:
            self.tefo_conf = json.load(data_file)
        tefo_conf = self.tefo_conf

        self.tefo_type = tefo_conf['tefo'].get('TEFO_type', 'dual')

        cfg = config.Config(i2c=tefo_conf['pymlab']['i2c'],  bus=tefo_conf['pymlab']['bus'])

        # An internal "pointer" to the ongoing action. After it's finished, it will be chanded 
        # to self.action_next ('None' means everything is completed).
        # There is a special case of action "calibrate", which consists of 3 subsequent 
        # sub-actions (and the switching to action_next will be performed only when the last 
        # one of them is completed).
        # Possible values: None, finished, move, stop, calibrate, calibrate1, calibrate2, calibrate3.
        self.action_now = None
        self.action_next = None

        # Timeout of the ongoing action (more specifically, the timestamp when it will expire)
        self.action_timeout = None

        # Result of the last action (ok = 0, fail/timeout = 1)
        self.lastaction_result = None

        self.last_set_position = None

        # A moment, at which the ongoing action should finish.
        self.expected_moveend_time = 0

        self.last_command_id = None

        self.sock = socket.socket(socket.AF_INET, socket.SOCK_DGRAM)
        self.sock.bind((tefo_conf['connection']['ip'], tefo_conf['connection']['port']))
        self.sock.setblocking(0)

        cfg.initialize()
        spi = cfg.get_device("spi")
        self.usbi2c = cfg.get_device("gpio")
        ##self.sensor = cfg.get_device("encoder")

        self.usbi2c.setup(0, self.usbi2c.OUT, self.usbi2c.PUSH_PULL)
        self.usbi2c.setup(1, self.usbi2c.OUT, self.usbi2c.PUSH_PULL)
        self.usbi2c.output(0, 0)
        self.usbi2c.output(1, 0)

        spi.SPI_config(spi.I2CSPI_MSB_FIRST| spi.I2CSPI_MODE_CLK_IDLE_HIGH_DATA_EDGE_TRAILING| spi.I2CSPI_CLK_461kHz)
        self.motor=axis.axis_between(SPI=spi, SPI_CS=spi.I2CSPI_SS0, StepsPerUnit=1)
        #self.motor.Reset(KVAL_RUN=0x29, KVAL_ACC=0x39, KVAL_DEC=0x39, FS_SPD=0xFFFFFF)

        kvals = tefo_conf['tefo']['kval']
        self.MAX_SPEED = tefo_conf['tefo']['speed']
        self.KVAL_ACC = kvals
        self.KVAL_RUN = kvals
        self.KVAL_DEC = kvals
        self.ACC = 100
        self.DEC = 100
        self.FS_SPD = 3000

        self.direction = tefo_conf['tefo']['dir']
        self.dirToHome = int (not self.direction);

        self.setup_motor()

        def_dir = False
        self.gpio_pins = [0,1]
        #data = {
        #    'dirToHome': def_dir,
        #    'self.gpio_pins': self.gpio_pins
        #    }

        #self.motor.search_range(False, self.usbi2c, self.gpio_pins)
        #sys.exit(0)

        #self.motor.Move(2000, 0)
        #self.motor.Wait()
        #self.motor.SoftStop ()
        #self.motor.Float()
        #sys.exit(1)


        # (a,b) = self.motor.validate_switch(self.usbi2c, self.gpio_pins)
        (a, b) = self.get_switch()
        print("Endstop states:", a, b)

        # Solving a problem, when the initial position is not within the allowed range 
        # (i.e. the endswitch is closed).
        # We discovered that the behaviour of the unit is a bit non-standard in such case. 
        # Some setup parameters seem to be ignored, including the microstep mode.
        # It's necessary to safely move into operational range (where the endswitch is open)
        # and repeat the initialization.
        if a or b:
            print("Moving slowly towards the operational range (releaseSW)")
            if b:   # the default case, when only one endswitch is present
                self.motor.ReleaseSW(direction=self.direction, ACT=False)
            elif a:
                self.motor.ReleaseSW(direction=self.dirToHome, ACT=False)
            if self.motor_wait_stop (timeout=60, message="ERROR: timeout while attempting to get into the operational range"):
                sys.exit(1)
            print("releaseSW should be finished")

            time.sleep(0.2)
            self.motor.MaxSpeed(self.tefo_conf['tefo']['release_speed'])
            time.sleep(0.2)

            # We move a bit farther to get from a "greyzone" where the endswitch could flutter...
            # The fluttering of the endswitch (common especially for IR sensors) can interrupt 
            # this process, so we may need to run it repeatedly.
            attempt = 0
            while True:
                print("inicialization release, Move attempt: ", attempt)
                self.motor.Move(tefo_conf['tefo'].get('release', 1000), self.direction, False, 'steps')
                if self.motor_wait_stop (timeout=10, message="timeout Move"):
                    sys.exit(1)
                if abs(self.motor.getPosition()) >= abs(tefo_conf['tefo'].get('release', 1000)):
                    print("success: ", abs(self.motor.getPosition()))
                    break
                else:
                    print("wrong position, probably interrupted by a flutter of the endswitch: ", abs(self.motor.getPosition()))
                attempt = attempt + 1
                if attempt > 10:
                    print("FAIL: unable to realize an initial release...")
                    sys.exit(1)
                time.sleep(0.2)

            time.sleep(0.5)

            # And repeat the initialization...
            self.setup_motor()


        # (a,b) = self.motor.validate_switch(self.usbi2c, self.gpio_pins)
        (a,b) = self.get_switch()
        print("Endstop states:", a, b)

        if self.motor.getStatus()['SW_F']:
            print("Safety check: the endstop is still closed, exiting...")
            sys.exit(0)

        if self.tefo_conf['tefo'].get("calib", True):
            self.calibrate()

        data = None
        command = None

        while True:
            #print("while run...")
            #print(self.sensor.get_angle(verify=True))

            #sys.stdout.write("RPS01A Angle: " + str(self.sensor.get_angle(verify=True)) + "\t\tMagnitude: " + str(self.sensor.get_magnitude())
            #    + "\tAGC Value: " + str(self.sensor.get_agc_value()) + "\tDiagnostics: " + str(self.sensor.get_diagnostics()) + "\r\n")
            #sys.stdout.flush()
            #print(self.motor.getStatus())

            # The select is used very minimalistically here, practically it's an equivalent of
            # a simple "sleep" method with an advantage of a prompt reaction to an incoming 
            # message.
            inputready,outputready,exceptready = select.select([self.sock],[],[],0.2)

            try:
                data = None
                data, addr = self.sock.recvfrom(1024)
                print("received message:", data, addr)
            except Exception as e:
                pass

            if data:
                try:
                    command = None
                    command_id, command = data.decode().split(' ')
                    #print("split result:", command_id, command)
                except Exception as e:
                    print("split exception:", e)
                    pass

            if command:
                #miss = self.is_misscalibrated()
                #ip, port = addr
                #self.sock.sendto("ACK;%s;%s;\n\r" %(data.strip(), ip), addr)

                if command_id == self.last_command_id:
                    request_status = "duplicity"

                #
                #   'S' parameter - get status
                #
                elif command[0] == 'S':
                    request_status = "accepted"

                #
                #   'Mxxxx' parameter - move to position (1-1000)
                #
                elif command[0] == 'M':
                    if self.action_now is not None and "calibrate" in self.action_now:
                        request_status = "wrong"
                    else:
                        request_status = "accepted"
                        target = int(command[1:])
                        if target > 1000: target = 1000
                        if target < 1: target = 1
                        if self.action_now == "stop" or self.action_now == "finished":
                            self.last_set_position = target
                            self.action_next = "move"
                        else:
                            self.move(target)

                #
                #   'CMxxxx' parameter - calibrate and move to position (1-1000)
                #
                elif 'CM' in command:
                    if self.action_now is not None and "calibrate" in self.action_now:
                        request_status = "wrong"
                    else:
                        request_status = "accepted"
                        target = int(command[2:])
                        if target > 1000: target = 1000
                        if target < 1: target = 1
                        if self.action_now == "stop" or self.action_now == "finished":
                            self.last_set_position = target
                            self.action_next = "calibrate"
                        else:
                            self.calibrate(target)

                #
                #   'C' parameter - (re)calibrate
                #
                elif command[0] == 'C':
                    if self.action_now is not None and "calibrate" in self.action_now:
                        request_status = "wrong"
                    else:
                        request_status = "accepted"
                        if self.action_now == "stop" or self.action_now == "finished":
                            self.action_next = "calibrate"
                        else:
                            self.calibrate()

                elif 'STOP' in command or 'stop' in command:
                    request_status = "accepted"
                    self.stop()

                else:
                    print("unknown command")
                    request_status = "wrong"


                if self.direction == 0:
                    posCoef = -1.0
                else:
                    posCoef = 1.0
                position = int(posCoef * self.motor.getPosition() / float(self.tefo_conf['tefo']['lenght']) * 1000.0 + 0.5)

                if self.motor.IsBusy():
                    if self.action_now == "move":
                        motor_status = "moving"
                    elif self.action_now is not None and "calibrate" in self.action_now:
                        motor_status = "calibrating"
                else:
                    motor_status = "idle"

                if self.action_now == "move":
                    time_to_moveend = self.expected_moveend_time - time.time()
                    if time_to_moveend < 0.0:
                        time_to_moveend = 0.0
                else:
                    time_to_moveend = 0.0

                message = "%s %s %s %s %s %s %s %s\n" %(command_id, command.rstrip(), request_status, motor_status, str(self.lastaction_result), str(position), str(self.last_set_position), str(time_to_moveend))
                self.sock.sendto(message.encode(), addr)

                self.last_command_id = command_id
                command = None

            else:
                # A place where all *_progress functions will be called
                # as well as timeouts being solved
                # as well as logic of switching next->now actions.
                if self.action_now is not None and time.time() > self.action_timeout:
                    print("Timeout!!!")
                    self.stop()
                    self.lastaction_result = 1  # fail

                if self.action_now == "finished":
                    if self.action_next:
                        if self.action_next == "move":
                            self.move();    # a target is taken from self.last_set_position
                        if self.action_next == "calibrate":
                            self.calibrate();   # a target is taken from self.last_set_position
                        self.action_next = None
                    else:
                        self.action_now = None
                elif self.action_now == "stop":
                    self.stop_progress()
                elif self.action_now == "move":
                    self.move_progress()
                elif self.action_now is not None and "calibrate" in self.action_now:
                    self.calibrate_progress()

                #time.sleep(0.2)

        self.motor.Float()

#    def is_misscalibrated(self):
#        print(self.last_pos)
#        #print(self.sensor.get_angle(verify=False))
#        diff = 0
#        #diff = abs(float(self.last_pos) - self.sensor.get_angle(verify=False))
#        if diff < 5:
#            return False
#        else:
#            return diff


    def stop(self):
        self.motor.SoftStop()
        self.action_timeout = time.time() + 3
        self.action_now = "stop"
        self.action_next = None     # if the movement should follow, it's necessary to set it explicitly AFTER calling of the stop() function!!!
        #self.last_pos = None
        self.last_set_position = None

    def stop_progress(self):
        if not self.motor.IsBusy():     # i.e., this phase just ended
            self.action_now = "finished"


    def calibrate(self, pos=None):
        print("Calibration started")

        # The calibration is concluded by a movement to a position
        # (the first defined/known wins, in this order):
        # 'pos', last set position, 'home' position.
        if not pos:
            if self.last_set_position:
                pos = self.last_set_position
            else:
                pos = self.tefo_conf['tefo'].get("home", 100)
                print("position obtained from cfg: ", pos)

        status = self.motor.getStatus()
        print(status)

        if status['BUSY'] == 1 or status['MOT_STATUS'] != 0:    # if moving, then stop
            self.stop()
            self.action_next = "calibrate"  # postpone the calibration till the stop is finished... the target position will be propagated via self.last_set_position (the logic of operation's interrupts excludes the conflict with the preceding operation)
        else:
            self.motor.MaxSpeed(self.tefo_conf['tefo'].get('home_speed', 100))
            print("Movement GoUntil")
            self.action_timeout = time.time() + 60
            self.motor.GoUntil(self.dirToHome, self.tefo_conf['tefo'].get('home_speed', 100))
            time.sleep(0.1)

            self.action_now = "calibrate1"
            self.action_next = "move"

        self.last_set_position = pos


    def calibrate_progress(self):
        #print("Calibration in progress")

        if self.action_now == "calibrate1":
            if not self.motor.IsBusy():     # i.e., this phase just ended
                ## HERE is the FIRST hit to ENDSWITCH
                print('GoUntil to endswitch finished')
                time.sleep(0.5)
                self.motor.ReleaseSW(direction=self.direction, ACT=False)
                print("waiting for release")
                self.action_timeout = time.time() + 30
                self.action_now = "calibrate2"
                time.sleep(0.1)

        if self.action_now == "calibrate2":
            if not self.motor.IsBusy():     # i.e., this phase just ended
                print('endswitch released')
                time.sleep(0.5)
                print(self.motor.getStatus())
                # Move yet further by an offset, to overcome the hysteresis area (where a fluttering can occure, 
                # which could endanger the prospective recalibration process)...

                print('calibration offset...')
                self.motor.MaxSpeed(self.tefo_conf['tefo'].get('release_speed', 200))
                move = self.tefo_conf['tefo'].get('calib_release', 100)
                if self.direction == 0:
                    move = -move
                self.motor.GoTo(move)
                self.action_timeout = time.time() + 5
                self.action_now = "calibrate3"
                time.sleep(0.1)

        if self.action_now == "calibrate3":
            if not self.motor.IsBusy():     # i.e., this phase just ended
                print('calibration offset finished...')
                print(self.motor.getStatus())

                time.sleep(0.5)
                self.motor.Float()
                self.motor.ResetPos()
                print(self.motor.getStatus())

                self.action_now = "finished"


    def move(self, pos=None):
        print("Move started")

        # If pos is not defined, I want to (the typical case of a post-calibration movement)
        # move to last set position or 'home' position.
        if not pos:
            if self.last_set_position:
                pos = self.last_set_position
            else:
                pos = self.tefo_conf['tefo'].get("home", 100)
                print("position obtained from cfg: ", pos)

        status = self.motor.getStatus()
        print(status)

        if status['BUSY'] == 1 or status['MOT_STATUS'] != 0:    # if moving, then stop
            self.stop ()
            self.action_next = "move"  # postpone the movement till the stop is finished... the target position will be propagated via self.last_set_position (the logic of operation's interrupts excludes the conflict with the preceding operation)
        else:
            self.motor.MaxSpeed(self.MAX_SPEED)

            move = int(self.tefo_conf['tefo']['lenght']*pos/1000.0)
            if self.direction == 0:
                move = -move

            distance = abs(move - self.motor.getPosition())
            if distance > self.MAX_SPEED**2 / self.ACC:
                self.expected_moveend_time = time.time() + self.MAX_SPEED/self.ACC + distance/(self.MAX_SPEED*16.0)   # 16 coeff used because of the microsteps chosen, see setup, hardcoded for now
            else:
                self.expected_moveend_time = time.time() + 2* math.sqrt(distance/(self.ACC*16.0))     # 16 coeff used because of the microsteps chosen, see setup, hardcoded for now

            print("expecting end of move in: ", self.expected_moveend_time)

            self.action_timeout = self.expected_moveend_time + 3.0

            print(time.time(), "Begin of GoTo")

            self.motor.GoTo(move)
            time.sleep(0.1)
            self.action_now = "move"

        self.last_set_position = pos

    def move_progress(self):
        #print(time.time(), "Move in progress...")

        if not self.motor.IsBusy():     # i.e., the movement is finished
            print(time.time(), 'Move finished')
            print(self.motor.getStatus())
            self.motor.Float()

            self.action_now = "finished"
            self.lastaction_result = 0  # success
            #TODO: possibly to add some check that we really reached the demanded position (and use it as a condition for setting of self.lastaction_result)?


    def get_switch(self):
        if self.tefo_type == 'dual':
            return self.motor.validate_switch(self.usbi2c, self.gpio_pins)
        elif self.tefo_type == 'single':
            return (self.motor.getStatus()['SW_F'], self.motor.getStatus()['SW_F'])

    def setup_motor(self):
        # Transition to newer axis class
        self.motor.Float()
        time.sleep(0.5)
        self.motor.Setup(MAX_SPEED = self.MAX_SPEED,
                       KVAL_ACC = self.KVAL_ACC,
                       KVAL_RUN = self.KVAL_RUN,
                       KVAL_DEC = self.KVAL_DEC,
                       ACC = self.ACC,
                       DEC = self.DEC,
                       FS_SPD = self.FS_SPD,
                       STEP_MODE = axis.axis.STEP_MODE_1_16)
                       #STEP_MODE = axis.axis.STEP_MODE_FULL)

        time.sleep(0.1)

        # Set external switch behaviour (to not provide HardStop interrupt)
        self.motor.setConfig(EN_VSCOMP=0b0, SW_MODE=0b1)
        # ten VSCOMP jsem mel puvodne zapnutej (0b1), ale na WF delal hroznej rachot, tak jsem ho zatim vypnul, budu to jeste testovat, az se opravi fokuser na padesatce

        time.sleep(0.5)
        self.motor.Float()
        self.motor.ResetPos()
        time.sleep(0.5)

    def motor_wait_stop(self, timeout=5, message="motor timeout"):
        self.motor.Wait(maximal_time=timeout, print_pos=False)
        if self.motor.IsBusy ():
            self.motor.SoftStop ()
            print(message)
            time.sleep(0.5)
            self.motor.Float()
            return 1
        else:
            return 0


def main():
    f = focuser()

if __name__ == '__main__':
    main()

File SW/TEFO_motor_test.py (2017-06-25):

#!/usr/bin/python
# -------------------------------------------
# HBSTEP01A Stepper Motor control Example
# -------------------------------------------

#uncomment for debbug purposes
#import logging
#logging.basicConfig(level=logging.DEBUG) 

import sys
import time
from pymlab import config


class axis:
    def __init__(self, SPI_CS, Direction, StepsPerUnit):
        ' One axis of robot '
        self.CS = SPI_CS
        self.Dir = Direction
        self.SPU = StepsPerUnit
        self.Reset()

    def Reset(self):
        ' Reset Axis and set default parameters for H-bridge '
        spi.SPI_write_byte(self.CS, 0xC0)      # reset
#        spi.SPI_write_byte(self.CS, 0x14)      # Stall Treshold setup
#        spi.SPI_write_byte(self.CS, 0xFF)  
#        spi.SPI_write_byte(self.CS, 0x13)      # Over Current Treshold setup 
#        spi.SPI_write_byte(self.CS, 0xFF)  
        spi.SPI_write_byte(self.CS, 0x15)      # Full Step speed 
        spi.SPI_write_byte(self.CS, 0x00)
        spi.SPI_write_byte(self.CS, 0xF0)
 
        spi.SPI_write_byte(self.CS, 0x09)      # KVAL_HOLD
        spi.SPI_write_byte(self.CS, 0xFF)

        spi.SPI_write_byte(self.CS, 0x0A)      # KVAL_RUN
        spi.SPI_write_byte(self.CS, 0xFF)

        spi.SPI_write_byte(self.CS, 0x0B)      # KVAL_ACC
        spi.SPI_write_byte(self.CS, 0xFF)

#        spi.SPI_write_byte(self.CS, 0x18)      # Config register
#        spi.SPI_write_byte(self.CS, 0b11000000)
#        spi.SPI_write_byte(self.CS, 0x88)
      
    def MaxSpeed(self, speed):
        ' Setup of maximum speed '
        spi.SPI_write_byte(self.CS, 0x07)       # Max Speed setup 
        spi.SPI_write_byte(self.CS, 0x00)
        spi.SPI_write_byte(self.CS, speed)  

    def ReleaseSW(self):
        ' Go away from Limit Switch '
        while self.ReadStatusBit(2) == 1:           # is Limit Switch ON ?
            spi.SPI_write_byte(self.CS, 0x92 | (~self.Dir & 1))     # release SW 
            while self.IsBusy():
                pass
            self.MoveWait(10)           # move 10 units away
 
    def GoZero(self, speed):
        ' Go to Zero position '
        self.ReleaseSW()

        spi.SPI_write_byte(self.CS, 0x82 | (self.Dir & 1))       # Go to Zero
        spi.SPI_write_byte(self.CS, 0x00)
        spi.SPI_write_byte(self.CS, speed)  
        while self.IsBusy():
            pass
        time.sleep(0.3)
        self.ReleaseSW()

    def Move(self, units):
        ' Move some distance units from current position '
        steps = units * self.SPU  # translate units to steps 
        if steps > 0:                                          # look for direction
            spi.SPI_write_byte(self.CS, 0x40 | (~self.Dir & 1))       
        else:
            spi.SPI_write_byte(self.CS, 0x40 | (self.Dir & 1)) 
        steps = int(abs(steps))     
        spi.SPI_write_byte(self.CS, (steps >> 16) & 0xFF)
        spi.SPI_write_byte(self.CS, (steps >> 8) & 0xFF)
        spi.SPI_write_byte(self.CS, steps & 0xFF)

    def MoveWait(self, units):
        ' Move some distance units from current position and wait for execution '
        self.Move(units)
        while self.IsBusy():
            pass

    def Float(self):
        ' switch H-bridge to High impedance state '
        spi.SPI_write_byte(self.CS, 0xA0)

    def ReadStatusBit(self, bit):
        ' Report given status bit '
        spi.SPI_write_byte(self.CS, 0x39)   # Read from address 0x19 (STATUS)
        spi.SPI_write_byte(self.CS, 0x00)
        data0 = spi.SPI_read_byte()           # 1st byte
        spi.SPI_write_byte(self.CS, 0x00)
        data1 = spi.SPI_read_byte()           # 2nd byte
        #print hex(data0), hex(data1)
        if bit > 7:                                   # extract requested bit
            OutputBit = (data0 >> (bit - 8)) & 1
        else:
            OutputBit = (data1 >> bit) & 1        
        return OutputBit

    
    def IsBusy(self):
        """ Return True if tehre are motion """
        if self.ReadStatusBit(1) == 1:
            return False
        else:
            return True

# End Class axis --------------------------------------------------



cfg = config.Config(
    i2c = {
        "port": 1,
    },

    bus = [
        {
            "type": "i2chub",
            "address": 0x70,
            "children": [
                { "name":"spi", "type":"i2cspi", "channel": 1, },
            ],
        },
    ],
)


cfg.initialize()

print "Stepper motor control example. \r\n"

spi = cfg.get_device("spi")

spi.route()

try:
    print "SPI configuration.."
    spi.SPI_config(spi.I2CSPI_MSB_FIRST| spi.I2CSPI_MODE_CLK_IDLE_HIGH_DATA_EDGE_TRAILING| spi.I2CSPI_CLK_461kHz)
    time.sleep(1)

    print "Axis inicialization"
    X = axis(spi.I2CSPI_SS0, 0, 641)    # set Number of Steps per axis Unit and set Direction of Rotation
    X.MaxSpeed(2)                      # set maximal motor speed 

    print "Axis is running"

    for i in range(5):
        X.MoveWait(50)      # move 50 unit forward and wait for motor stop
        time.sleep(0.5)
        X.MoveWait(-50)     # move 50 unit backward and wait for motor stop
        time.sleep(0.5)

    X.Float()   # release power


finally:
    print "stop"

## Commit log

2017-06-25 TEFO01B - from MLAB svn
    [Letters.dxf, MLAB_logo.scad, TEFO01B_BOX01A.scad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]
2018-02-05 CPU usage issue # Please enter the commit message for your changes. Lines starting
    [TEFO_abspos.py]
2018-04-06 Wf and Main working, issue with SW release...
    [TEFO_abspos.py]
2019-11-27 TEFO01C box
    [Letters.dxf, MLAB_logo.scad, TEFO01C_BOX01A.scad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]
2021-02-11 Revise code and resolve undocumented behaviour
    I've deeply revised a strange behaviour of the unit and discovered
    an undocumented states, related to situation, when the unit is
    initialized with the "endstop closed".
    This code is an integration of my findings and should provide a safe
    and effictive way to resolve these inconsistencies.
    Also, some other minor changes were conducted, to improve and/or repair
    the correct behaviour.
    [TEFO_abspos.py]
2021-02-12 Add python3 compatibility, fix bugs
    [TEFO_abspos.py, TEFO_abspos_responsive.py]
2021-03-18 Remove bugs, add daemon-reload to readme
    [TEFO_abspos_responsive.py]
2021-03-23 Correct motor direction in BART's config
